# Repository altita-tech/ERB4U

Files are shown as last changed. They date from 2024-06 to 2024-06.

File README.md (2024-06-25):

# ERB API & Example Code

 


- [English](README.md)
- [中文](README.zh-CN.md)

* **The ERB4U series is a relay module programmable via USART serial port.**
* **A PC needs only one USB Type-C cable to simultaneously read/control multiple daisy-chained relay modules.**
* **Individual Relay Output:** Up to 30VDC/10A, 1NO + 1NC
* **Total Relay Output:** Up to 30VDC/32A
* **Working Principle:** The ERB4U device receives commands from USB or J1 connector (USART1) and passes the original commands to downstream ERB4U devices through the J6 connector (USART2) to achieve expandable functionality. Upon receiving a command, the ERB4U checks its own address and will only act if the address is correct.
* **USART Functionality**
    - **USART Parameters:** 115200 baud rate, 8 data bits, 1 stop bit, odd parity, no flow control
    - **Read Commands:** Temperature, relay status, PN/SN, and other information of single/multiple ERB4Us
    - **Write Commands:** Turn ON/OFF status of single/multiple relays
* **Address Setting:** 4-bit DIP switch sets addresses from 0 to 15, with multiple ERB4Us able to use the same address simultaneously
* **Protection Circuits**
    - Input reverse polarity protection
    - Optocoupler relay isolation between MCU and relay
    - Supports resistive (R) or inductive (L) loads
* **Python API & Example Code:** Available for download from GitHub
* **Operating Temperature:** -40 to 85 ℃

<table style="width:100%; text-align:center;">
  <tr>
    <td style="width: 50%;">
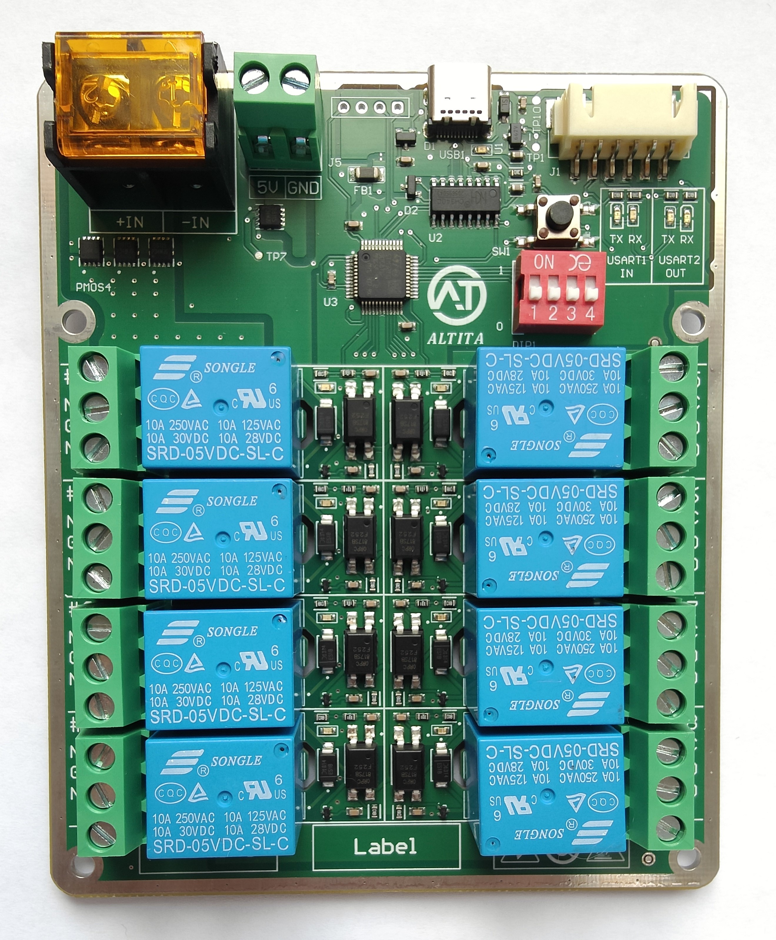
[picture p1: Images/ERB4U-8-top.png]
      
    </td>
    <td style="width: 50%;">
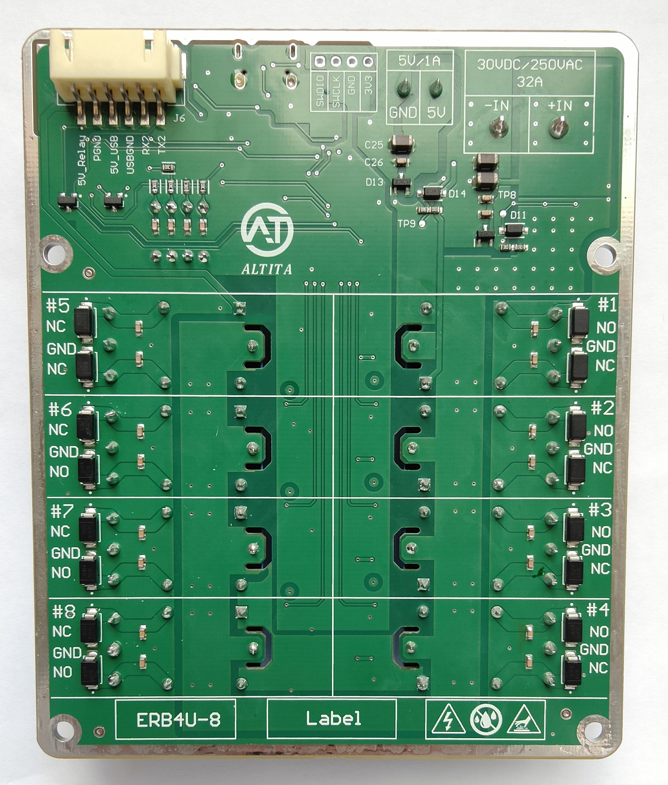
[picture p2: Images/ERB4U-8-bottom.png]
      
    </td>
  </tr>
</table>
<div style="text-align: center; margin: 10px;">
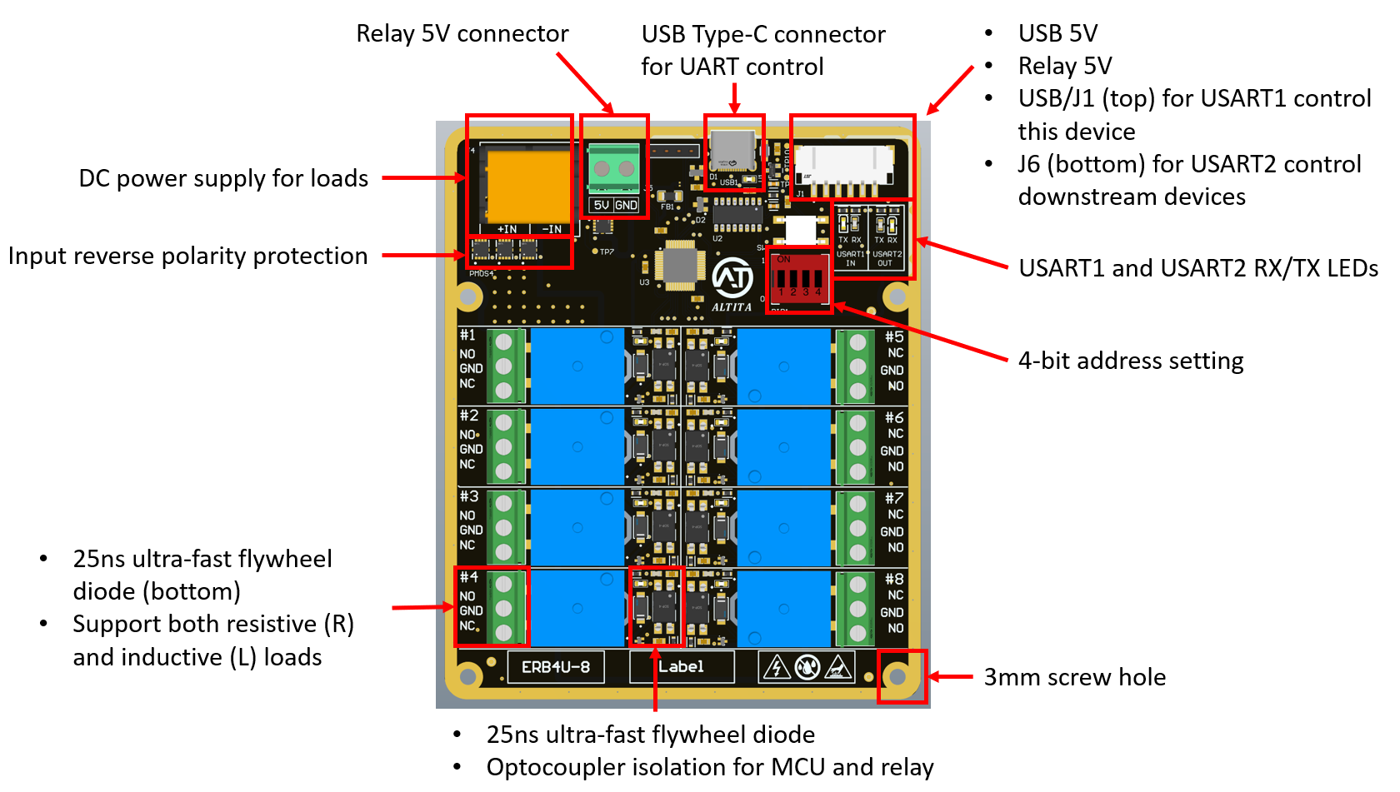
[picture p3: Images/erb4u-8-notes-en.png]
    
</div>

<div style="text-align: center; margin: 10px;">
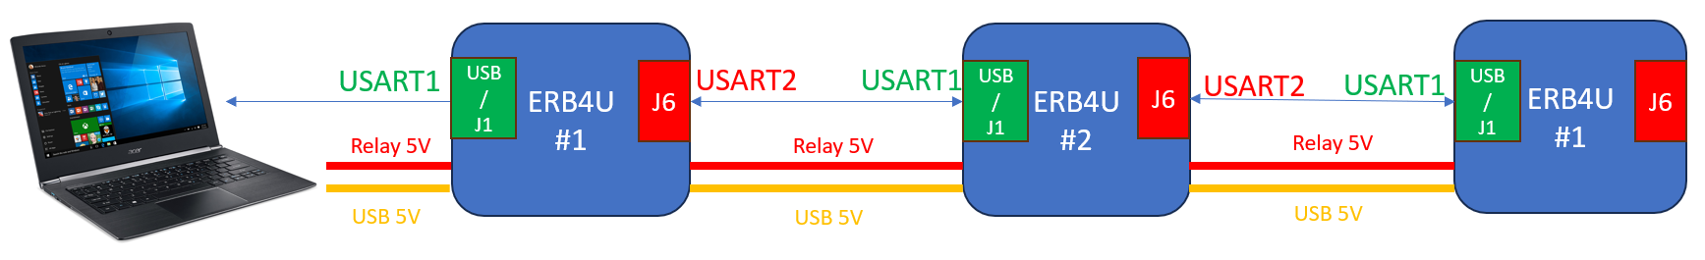
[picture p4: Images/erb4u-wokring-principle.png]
    
</div>

<table style="width:100%; text-align:center;">
  <tr>
    <td style="width: 50%;">
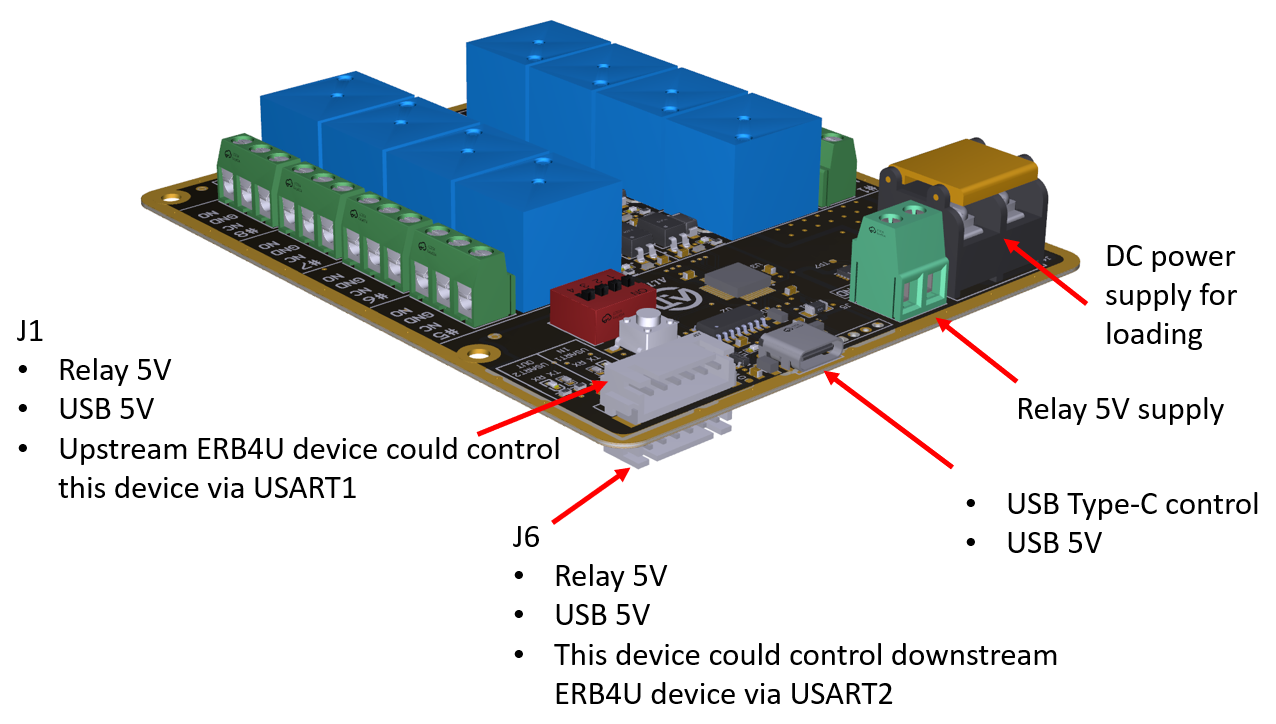
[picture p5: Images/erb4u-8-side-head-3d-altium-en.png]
      
    </td>
    <td style="width: 50%;">
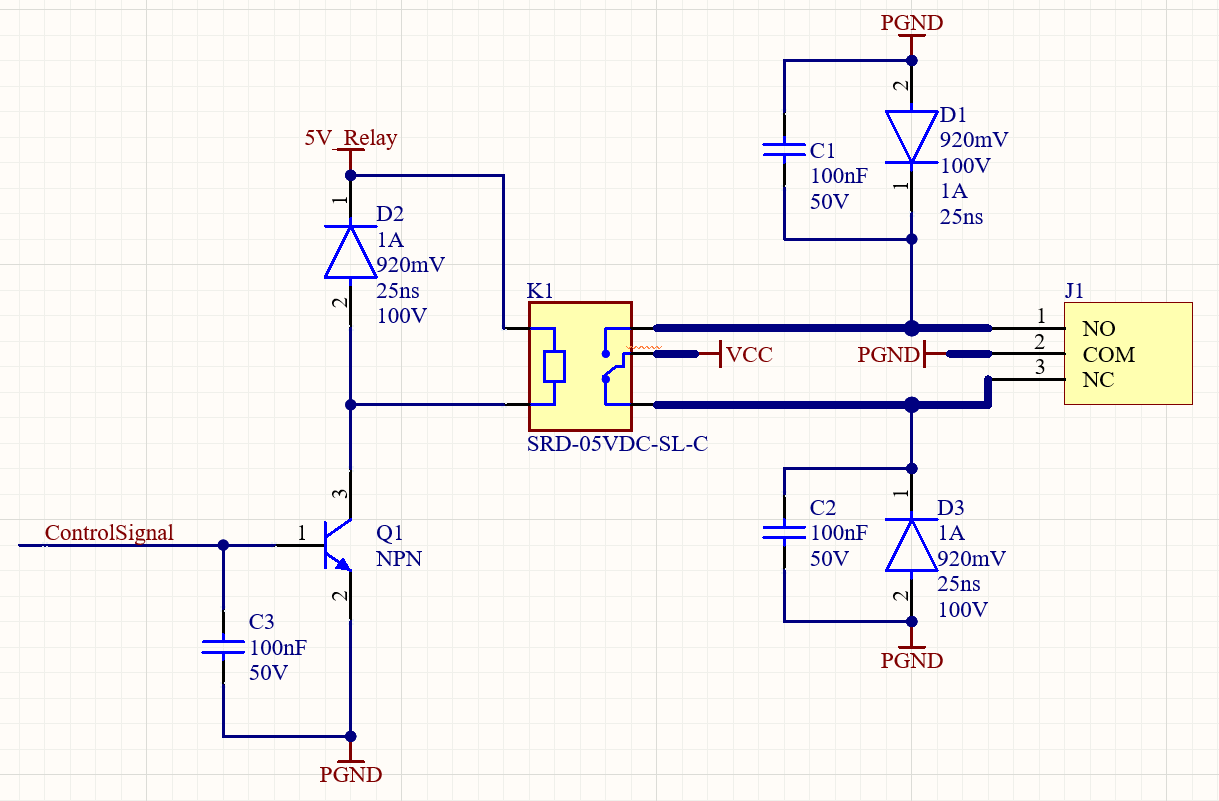
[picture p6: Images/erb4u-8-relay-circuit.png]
      
    </td>
  </tr>
</table>

## Communication Protocol
### Read Command
<div style="display: flex; justify-content: center;">
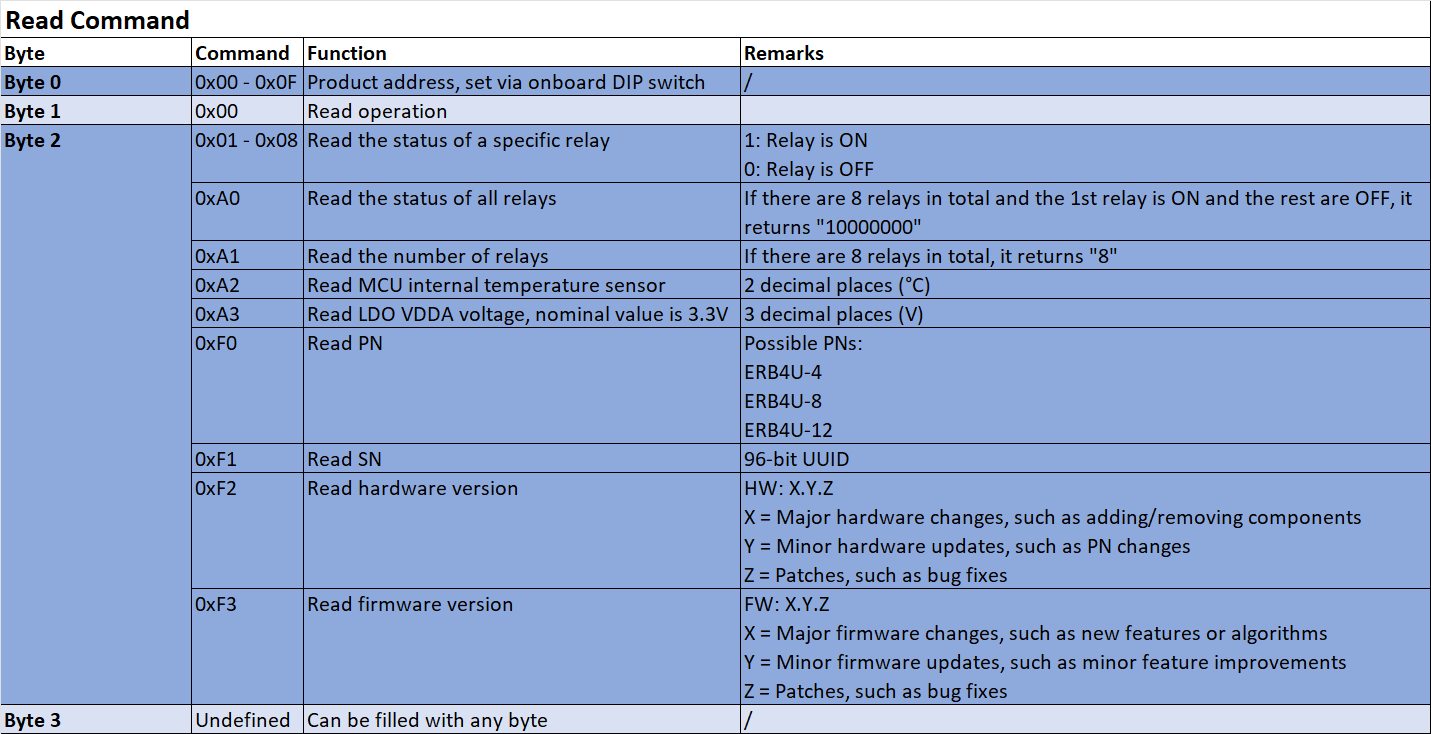
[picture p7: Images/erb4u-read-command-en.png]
  
</div>

### Write Command
<div style="display: flex; justify-content: center;">
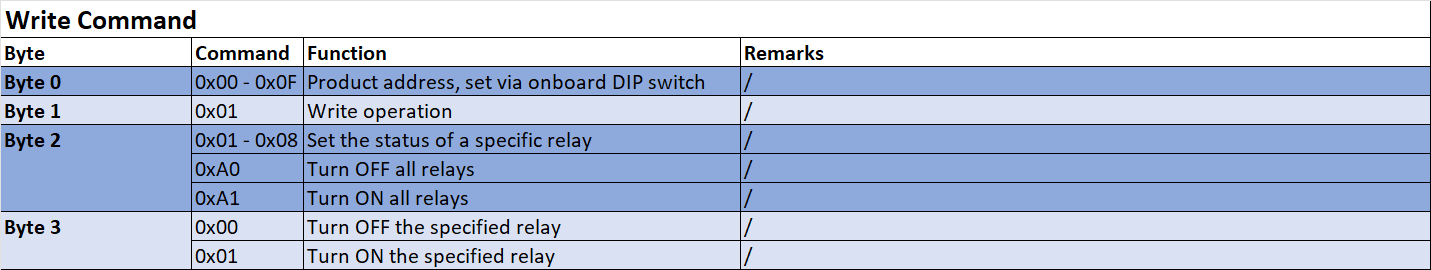
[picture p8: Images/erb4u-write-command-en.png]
  
</div>

### Error Message
<div style="display: flex; justify-content: center;">
  
</div>

## Drawings
### 2D Drawings: [Download](https://altita-tech.com/wp-content/uploads/ERB4U/ERB4U-8%202D.zip)
<table style="width:100%; text-align:center;">
  <tr>
    <td style="width: 50%; padding: 10px;">
      <div style="display: flex; justify-content: center;">
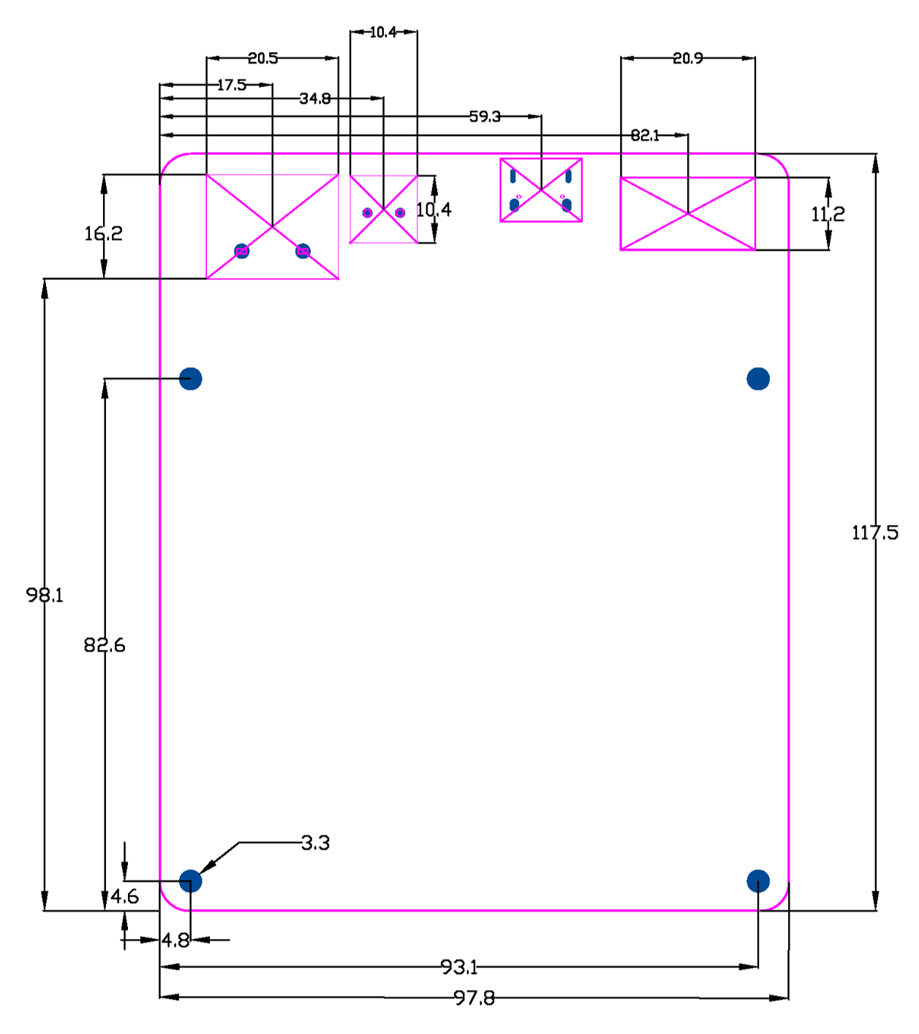
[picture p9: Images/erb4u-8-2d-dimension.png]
        
      </div>
    </td>
  </tr>
</table>

### 3D Model: [Download](https://altita-tech.com/wp-content/uploads/PBT223/PBT223%203D.zip)
<table style="width:100%; text-align:center;">
  <tr>
    <td style="width: 40%;">
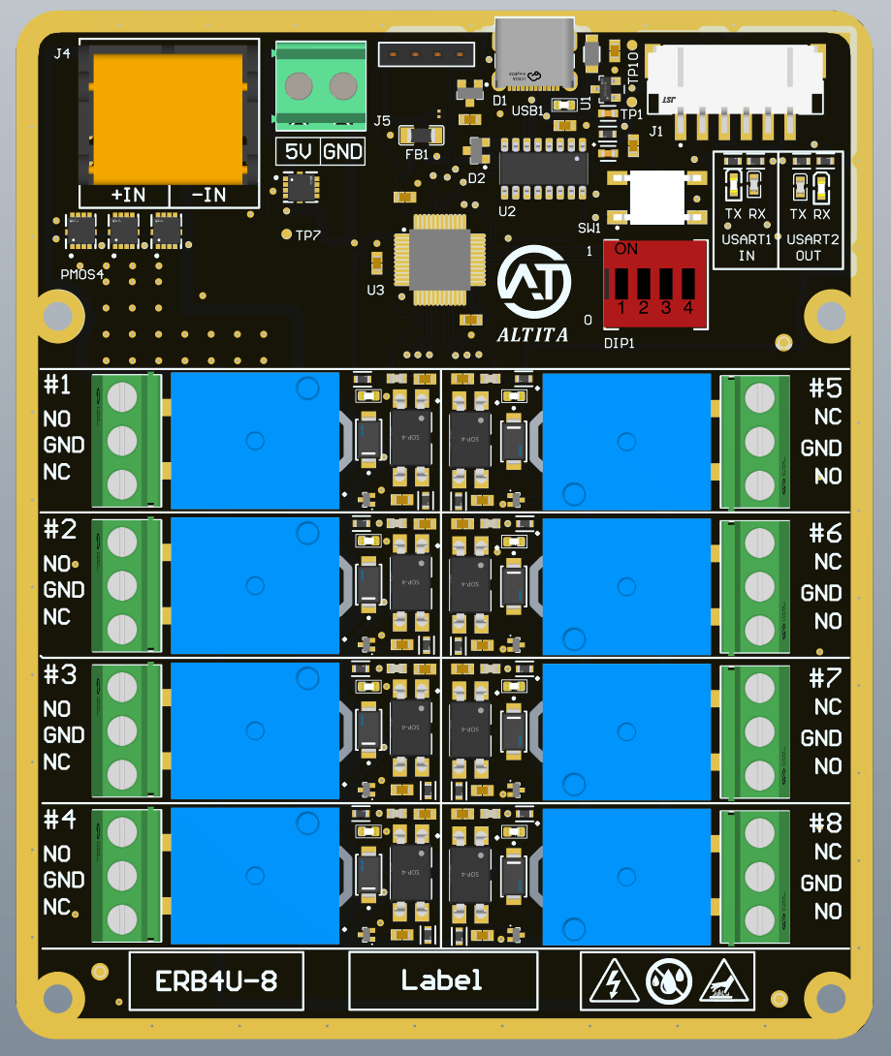
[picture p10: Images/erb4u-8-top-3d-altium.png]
      
    </td>
    <td style="width: 40%;">
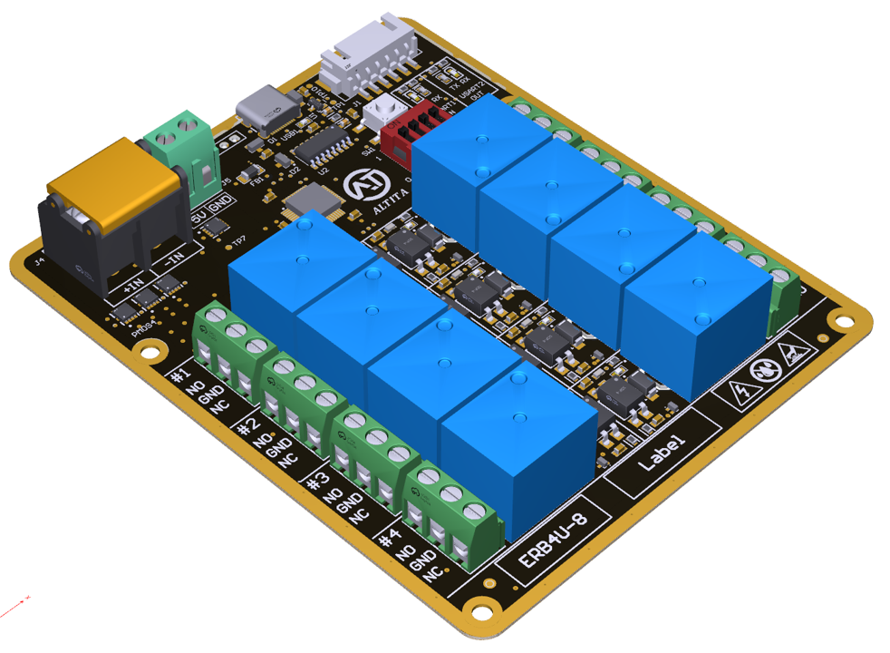
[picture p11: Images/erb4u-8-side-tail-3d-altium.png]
      
    </td>
  </tr>
</table>

## Functional Block Diagram
<table style="width:100%; text-align:center;">
  <tr>
    <td style="width: 100%;">
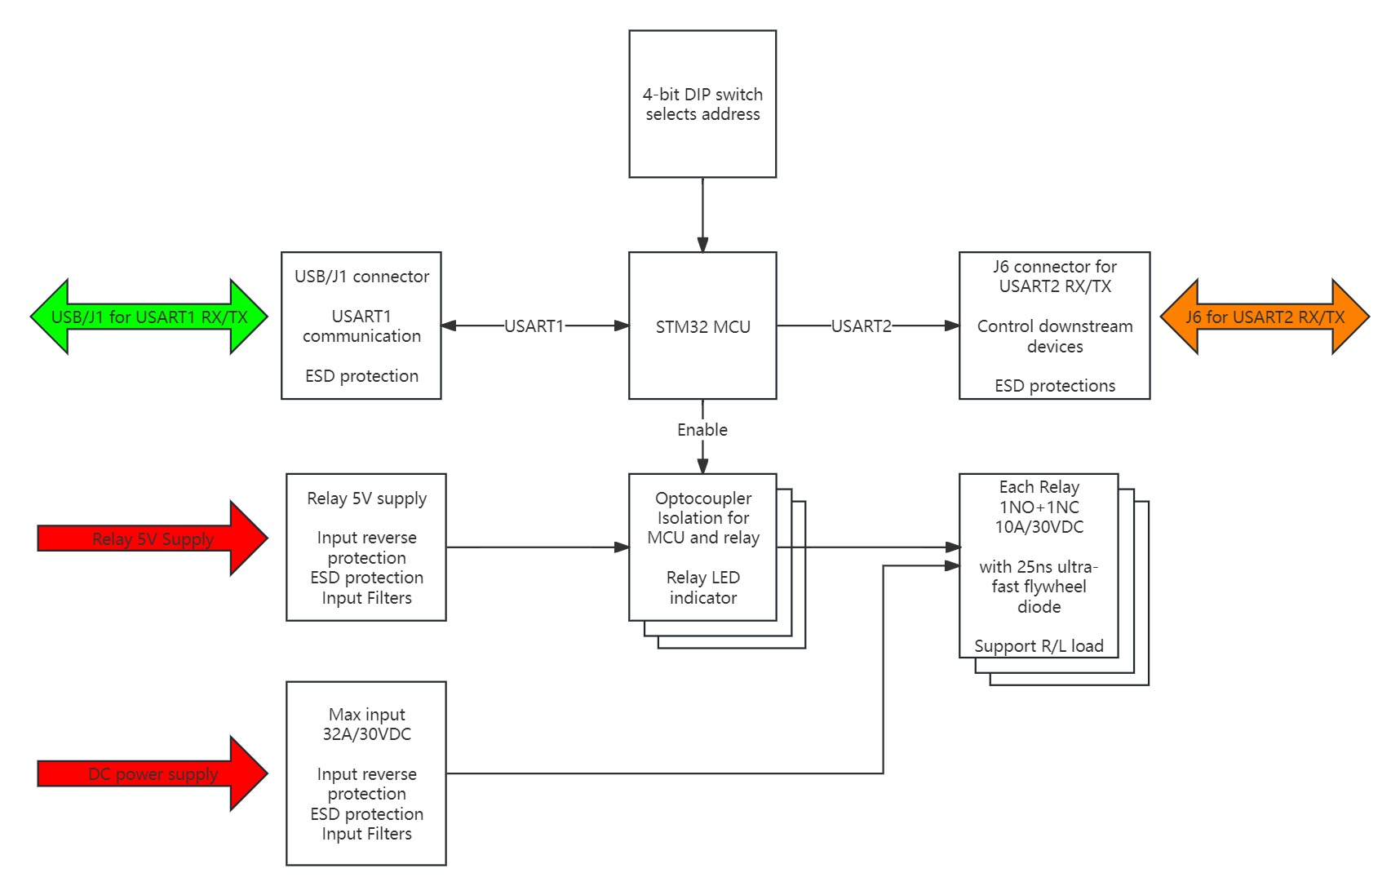
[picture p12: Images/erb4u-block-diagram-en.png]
      
    </td>
  </tr>
</table>

## Video Tutorial
YouTube Video (https://www.youtube.com/watch?v=MFrZ_5qzL38)

## Contact Us
<div style="display: flex; justify-content: space-between; align-items: flex-start;">
  <div>
    <ul style="list-style-type: disc; padding-left: 20px; margin: 0;">
      <li><strong>Company Website:</strong> <a href="https://altita-tech.com/">https://altita-tech.com/</a></li>
      <li><strong>Sales:</strong> <a href="mailto:sales@altita-tech.com">sales@altita-tech.com</a></li>
      <li><strong>Technical Support:</strong> <a href="mailto:tech@altita-tech.com">tech@altita-tech.com</a></li>
    </ul>
  </div>
</div>

<table style="width:100%; text-align:center;">
  <tr>
    <td style="width: 100%;">
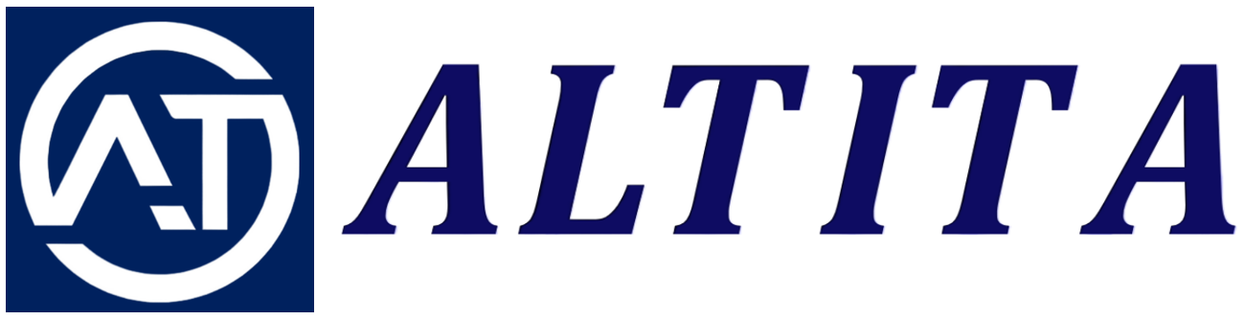
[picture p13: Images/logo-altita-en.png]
      
    </td>
  </tr>
</table>

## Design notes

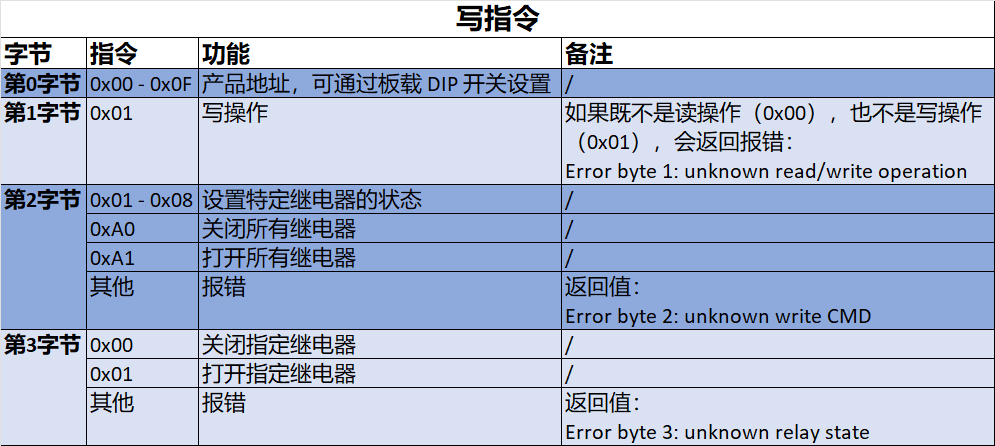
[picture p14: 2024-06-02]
Images/erb4u-write-command-cn.png

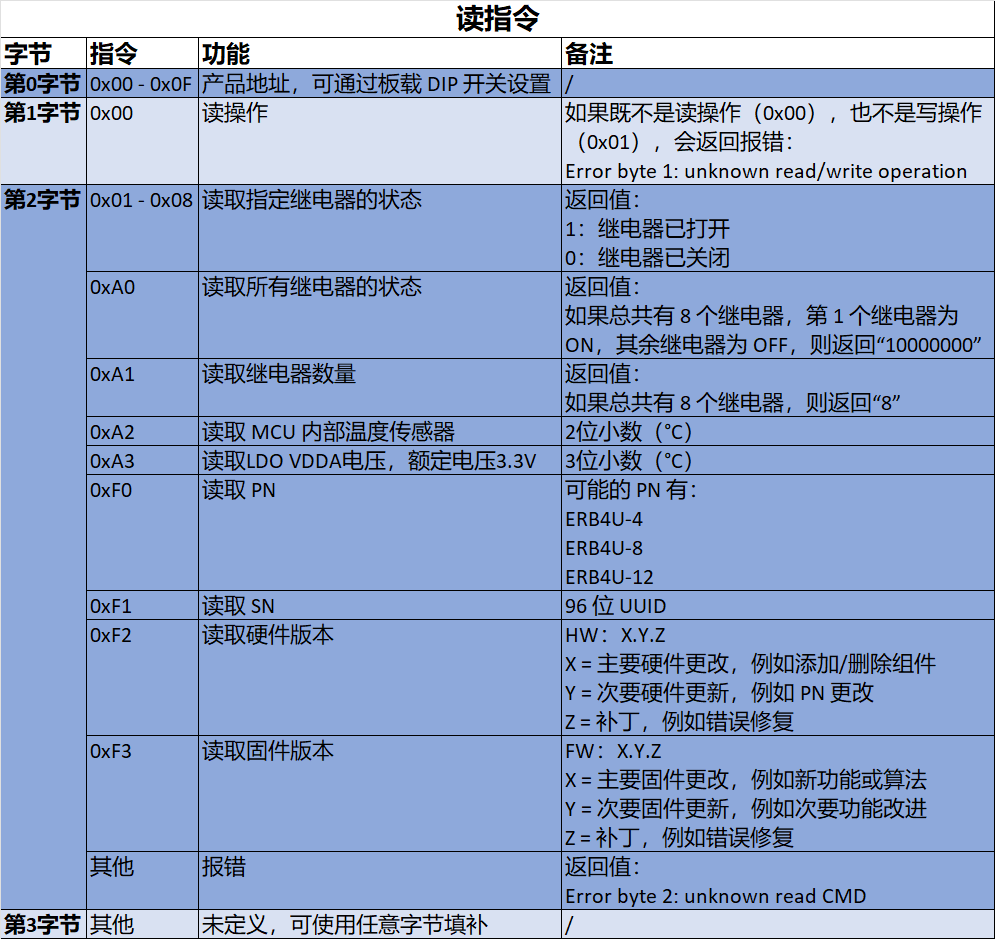
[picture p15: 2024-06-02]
Images/erb4u-read-command-cn.png

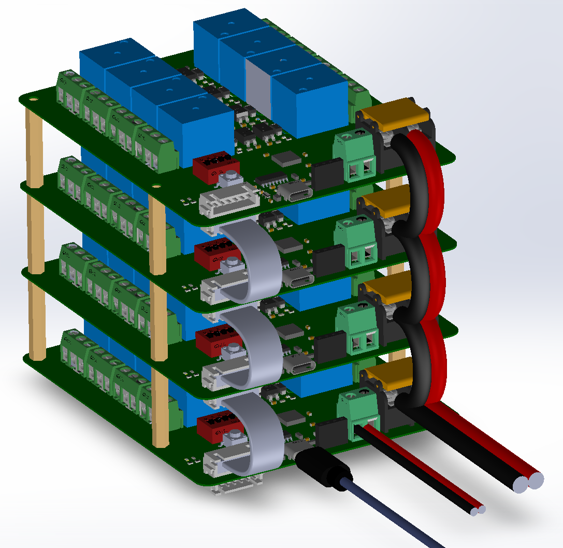
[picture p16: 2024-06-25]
Images/erb4u-8-layers-3d-solidworks.png

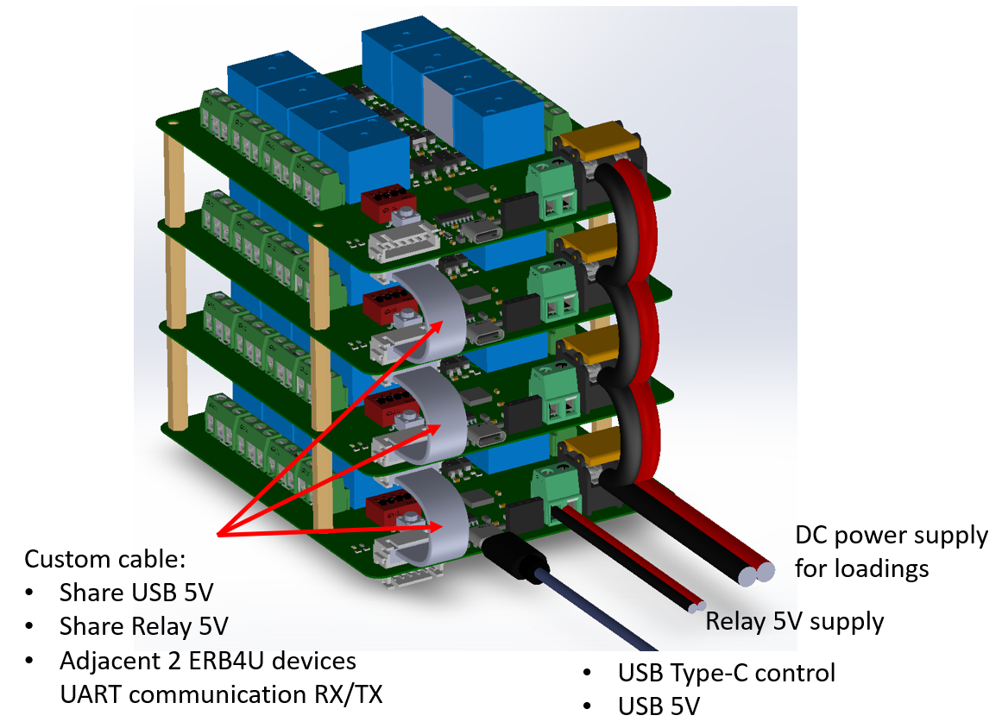
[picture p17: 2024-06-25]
Images/erb4u-8-layers-3d-solidworks-en.png

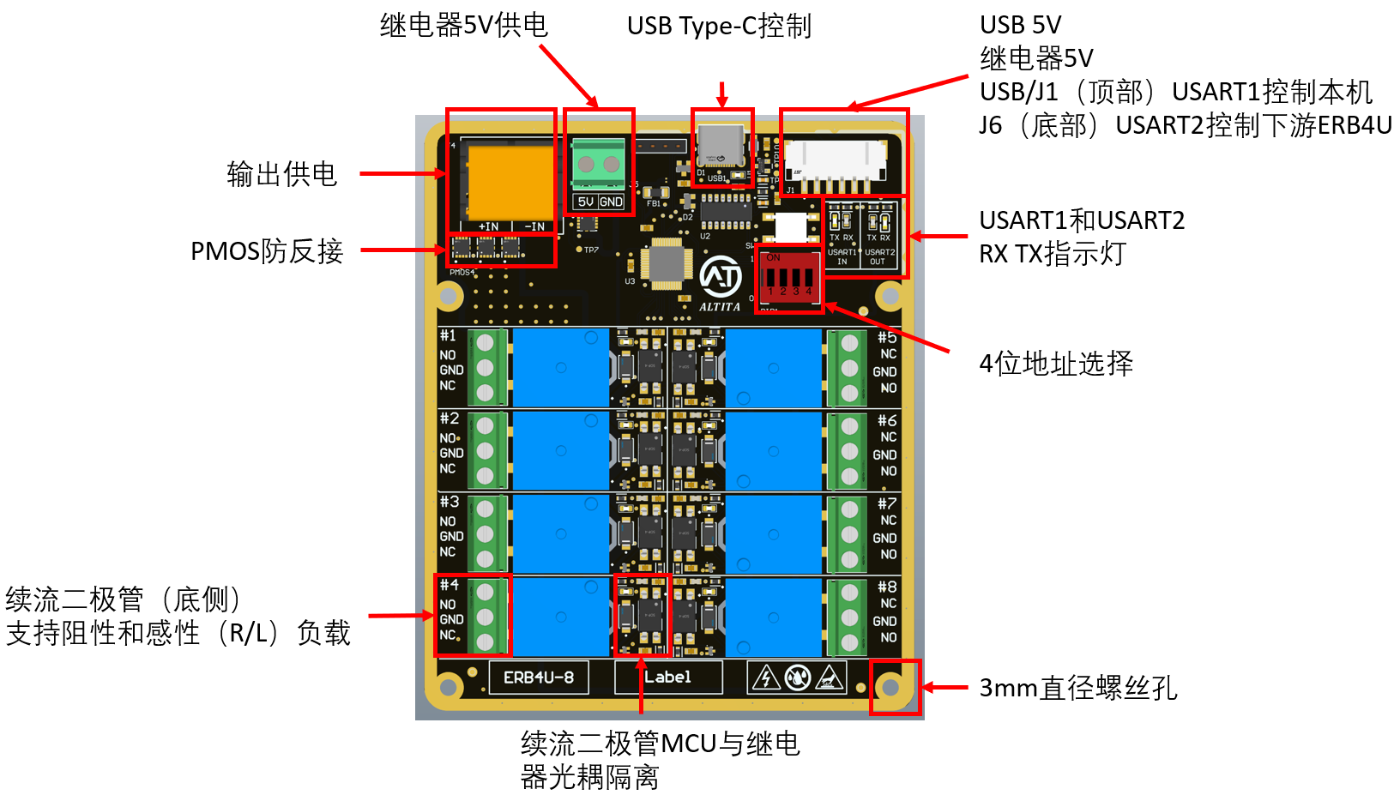
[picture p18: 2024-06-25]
Images/erb4u-8-notes-cn.png

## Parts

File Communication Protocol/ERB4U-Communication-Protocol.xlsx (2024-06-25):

Read Command
Byte | Command | Function | Remarks
Byte 0 | 0x00 - 0x0F | Product address, set via onboard DIP switch | /
Byte 1 | 0x00 | Read operation
Byte 2 | 0x01 - 0x08 | Read the status of a specific relay | 1: Relay is ON 0: Relay is OFF
 | 0xA0 | Read the status of all relays | If there are 8 relays in total and the 1st relay is ON and the rest are OFF, it returns "10000000"
 | 0xA1 | Read the number of relays | If there are 8 relays in total, it returns "8"
 | 0xA2 | Read MCU internal temperature sensor | 2 decimal places (°C)
 | 0xA3 | Read LDO VDDA voltage, nominal value is 3.3V | 3 decimal places (V)
 | 0xF0 | Read PN | Possible PNs: ERB4U-4 ERB4U-8 ERB4U-12
 | 0xF1 | Read SN | 96-bit UUID
 | 0xF2 | Read hardware version | HW: X.Y.Z X = Major hardware changes, such as adding/removing components Y = Minor hardware updates, such as PN changes Z = Patches, such as bug fixes
 | 0xF3 | Read firmware version | FW: X.Y.Z X = Major firmware changes, such as new features or algorithms Y = Minor firmware updates, such as minor feature improvements Z = Patches, such as bug fixes
Byte 3 | Undefined | Can be filled with any byte | /
Write Command
Byte | Command | Function | Remarks
Byte 0 | 0x00 - 0x0F | Product address, set via onboard DIP switch | /
Byte 1 | 0x01 | Write operation | /
Byte 2 | 0x01 - 0x08 | Set the status of a specific relay | /
 | 0xA0 | Turn OFF all relays | /
 | 0xA1 | Turn ON all relays | /
Byte 3 | 0x00 | Turn OFF the specified relay | /
 | 0x01 | Turn ON the specified relay | /
Error Message
Byte 1 Error | Error byte 1: unknown read/write operation
Byte 2 Error (Read) | Error byte 2: unknown read CMD
Byte 2 Error (Write) | Error byte 2: unknown write CMD
Byte 3 Error (Write) | Error byte 3: unknown relay state

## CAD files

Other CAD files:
2D/erb4u-8-2d-dxf.dxf
2D/erb4u-8-2d-dwg.DWG

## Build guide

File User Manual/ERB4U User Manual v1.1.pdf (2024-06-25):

www.altita-tech.com

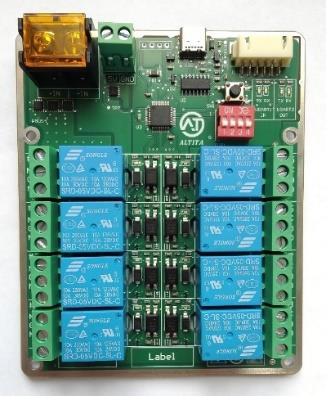
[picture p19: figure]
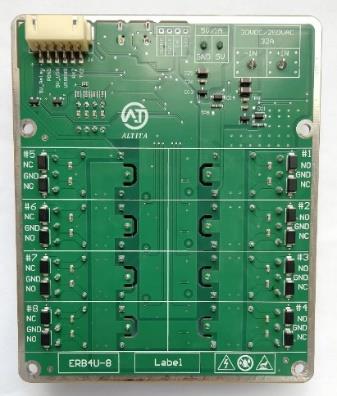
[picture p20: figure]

Copyright ©2024 奥提塔（上海）电子科技有限公司 | 1

# ERB4U Relay Module User Manual

# Extensible, Programmable, Max 30VDC/32A

# Product Overview

ERB4U series is a relay module that can be programmed through a USART serial port. Only 1 USB Type-C cable is required to read/control multiple relay modules simultaneously.

- Each Relay: max 30VDC/10A, 1 NO + 1 NC
- Total Relays: max 30VDC/32A
- Working Principle: The ERB4U device receives USART commands from the USB or J1 connector (USART1) and passes the original USART commands to downstream ERB4U devices through the J6 connector (USART2). Therefore, multiple ERB4U modules can be controlled by 1 USB type-C cable from PC. Upon receiving a command, the ERB4U will check its local address and will only execute the action if the address matches.
- USART Functionality
- USART Parameters: 115200 baud rate, 8 data bits, 1 stop bit, odd parity, no flow control
- Read Commands: read temperature, 1 or multiple relay status, PN/SN, etc
- Write Commands: turn ON/OFF 1 or multiple relays
- Address Setting: 4-bit DIP Switch: Sets the address from 0 to 15; multiple ERB4Us can share the same address.
- Protection Circuits
- Input Reverse Polarity Protection
- Optocoupler Relay Isolation: between MCU and relay
- Output Protection: support resistive (R) or inductive (L) loads
- Python API & Example Codes: can be downloaded from GitHub
- Operating Temperature: -40 to 85 ℃
Figure 1 ERB4U-8 real top | Figure 2 ERB4U-8 real bottom

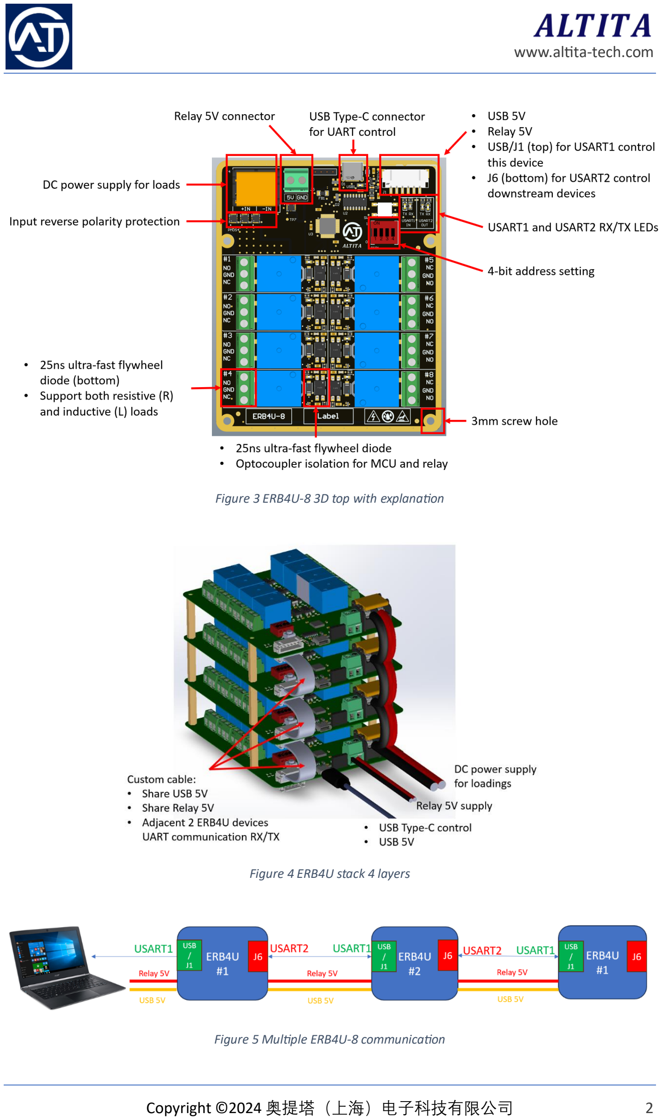
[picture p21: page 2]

Figure 3 ERB4U-8 3D top with explanation

Figure 4 ERB4U stack 4 layers

Figure 5 Multiple ERB4U-8 communication

# Applications

- Industrial Automation Control
- Automated Test Equipment
- Embedded Electronic Devices
- Universities, Research Institutions, Laboratories
- STEM Education, Training Institutes

# Version Control

Version | Release Date | Description and Changes
1.0 | May 1, 2024 | Initial release version
1.1 | May 30, 2024 | Added command for reading LDO VDDA

## Table of Content

## 1 Electrical Parameters

### 1.1 Relays

- Upon startup, all relays are OFF by default
- Each relay output: max 30VDC/10A, 1 NO + 1 NC
- Optocoupler relay isolation between MCU and relay
- Relay output includes a 25ns ultra-fast freewheeling diode, supporting both resistive and inductive loads (e.g., solenoids, motors)

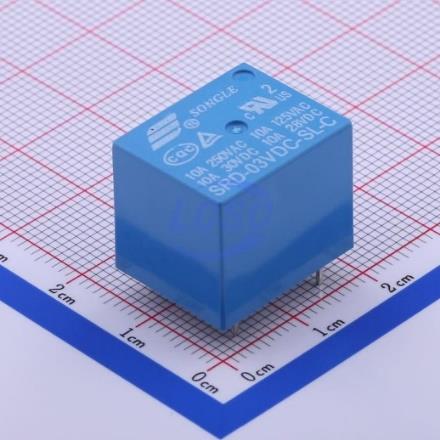
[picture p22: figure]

Figure 6 Relay 30VDC/10A

### 1.2 Address Setting

Manually select device address via 4-bit DIP switch, ranging from 0x00 to 0x0F.

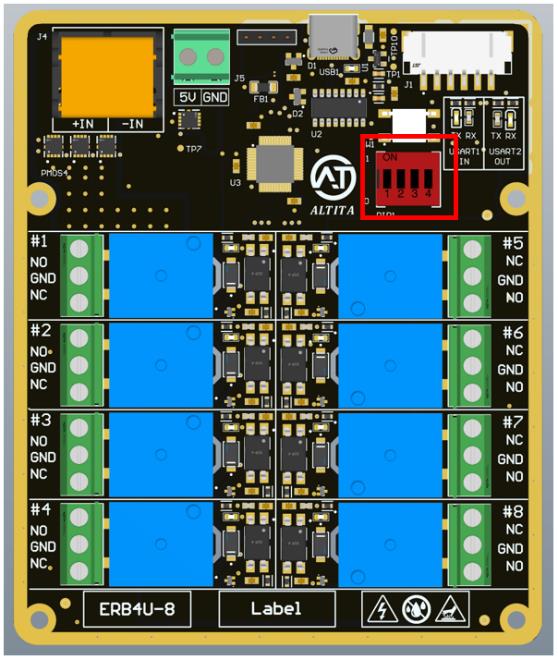
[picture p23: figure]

Figure 7 ERB4U 4-bit DIP switch

### 1.3 USART Communication

Only need 1 single USB Type-C cable connects the PC to the ERB4U module, enabling USART serial read/write functionality.

Parameter | Value
Communication Mode | • USART1 connects to USB Type-C and J1 connector for communication with PC or upstream ERB4U relay module • USART2 connects to J6 connector for communication with downstream ERB4U relay module.
Baud Rate | 115200
Data Bits | 8
Stop Bits | 1
Parity | Odd
Flow Control | None
If additional relays are needed, connect the upstream ERB4U's J6 connector to the downstream ERB4U's J1 connector using a custom cable (PN: S108520017, Manufacturer: Ckmtw). The operational principle is as follows:
- USB and J1 connector (top) connect to USART1.
- J6 connector (bottom) connects to USART2.
- When the PC or upstream ERB4U module sends a write command to the ERB4U, the command is received via USB or J1 connector (USART1) and then transmitted to the next ERB4U via J6 connector (USART2), enabling expandability.
- The custom cable is used for sharing USB 5V and relay 5V power, also used for USART RX/TX communication between 2 adjacent ERB4U modules.
- Upon receiving the command, the ERB4U checks its address. If the address matches, the ERB4U executes the corresponding action. If not, the command is ignored.
- For specific USART commands, refer to the section <Communication Protocol>.

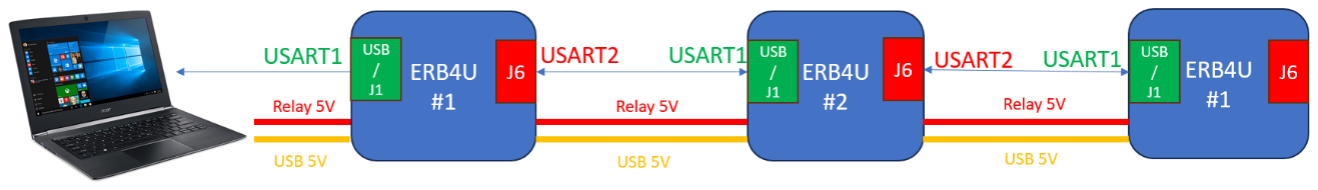
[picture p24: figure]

Figure 8 Multiple ERB4U-8 communication

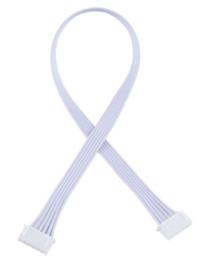
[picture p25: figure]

Figure 9 Custom cable for multiple ERB4U communication

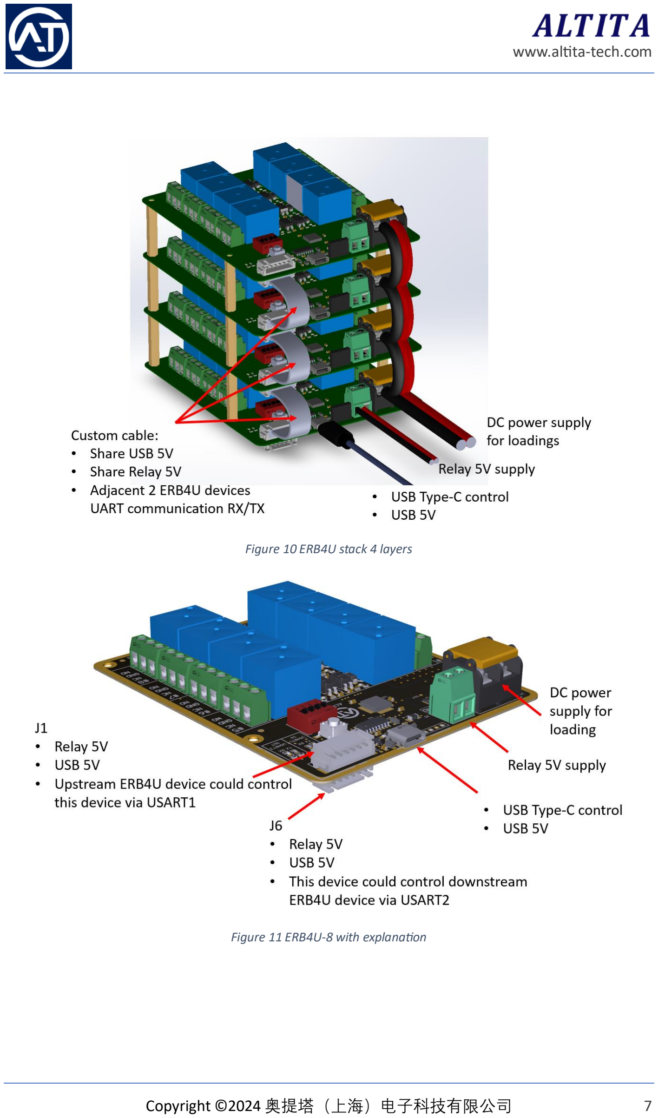
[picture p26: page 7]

Figure 10 ERB4U stack 4 layers

Figure 11 ERB4U-8 with explanation

### 1.4 LED

- USB Power: green LED
- Relay Status: green LED
- USART1 TX: blue LED
- USART1 RX: yellow LED
- USART2 RX: blue LED
- USART2 TX: yellow LED

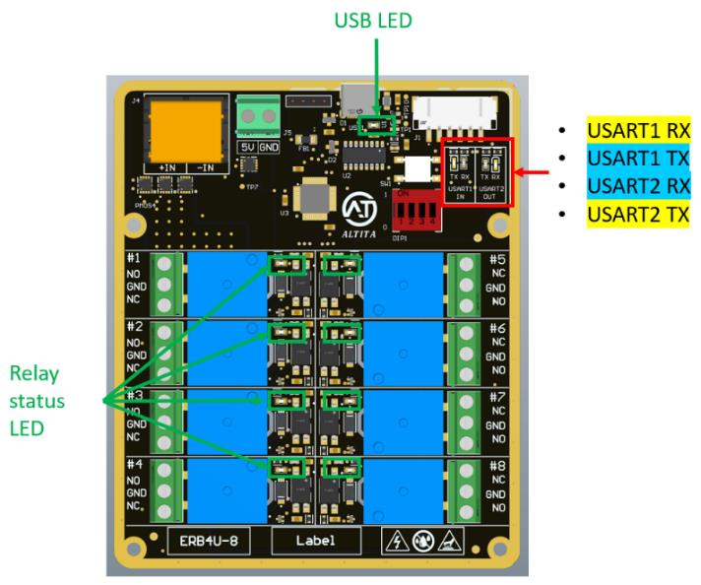
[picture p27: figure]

Figure 12 ERB4U-8 LEDs

### 1.5 Reset Button

- Pressing the reset button restarts the MCU, and all relays return to their default OFF state.

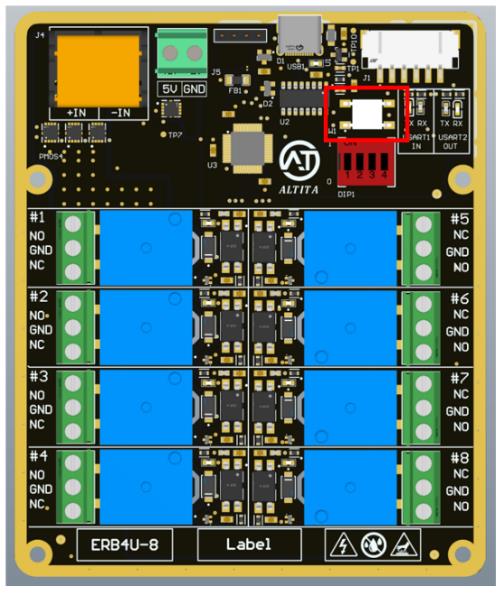
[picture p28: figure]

Figure 13 ERB4U-8 reset button

### 1.6 Operating Temperature

- -40 to 85 ℃
- The MCU internal temperature sensor will measure the temperature value, and you may obtain the temperature value via UART command (Python API).

## 2. Protection Circuits

### 2.1 Input Reverse Polarity Protection

- Both relay 5V connector and DC power connector have reverse input protection.
- Due to the conduction resistance Rds_on of PMOS, PMOS IC heats up when current flows through it. Typically, the PMOS is the hottest area on the ERB4U module. The temperature can be calculated using the following formula:

PMOS Temperature = Room Temperature + (Loading Current)^2 *0.4133

- Temperature Unit: Degree Celsus ℃
- Current Unit: A

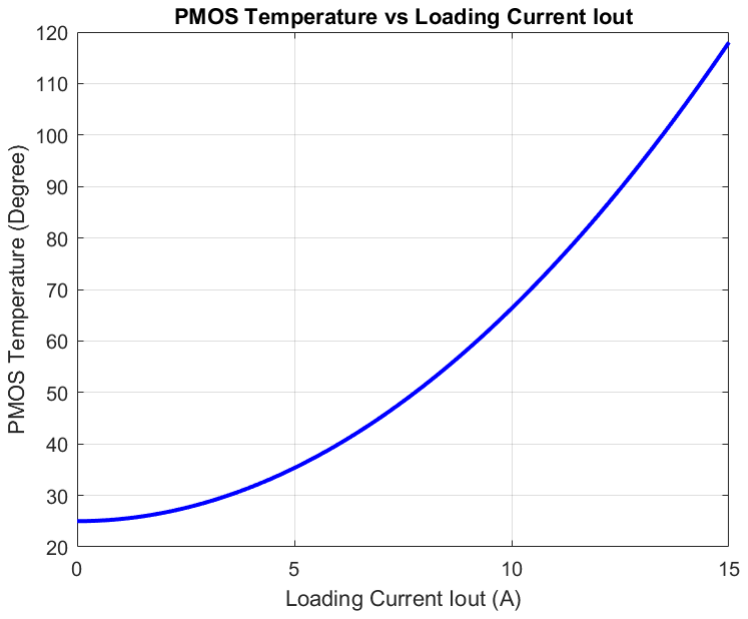
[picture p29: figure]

- It is recommended that the total continuous input current < 15A.
- If the total input current > 15A, a heat sink or cooling fan is required for PMOS.

### 2.2 Optocoupler Relay Isolation between MCU and Relay

Since the MCU operates at a low voltage of 3.3V and low current (mA level), while the relay operates at the high voltage and high current (such as 24VDC, 10A), an Optocoupler relay is used for isolation between MCU and relay.

- The MCU uses a 0V or 3.3V GPIO to enable of disable the Optocoupler relay.
- The Optocoupler relay output is 5V, which is used to activate the relay.

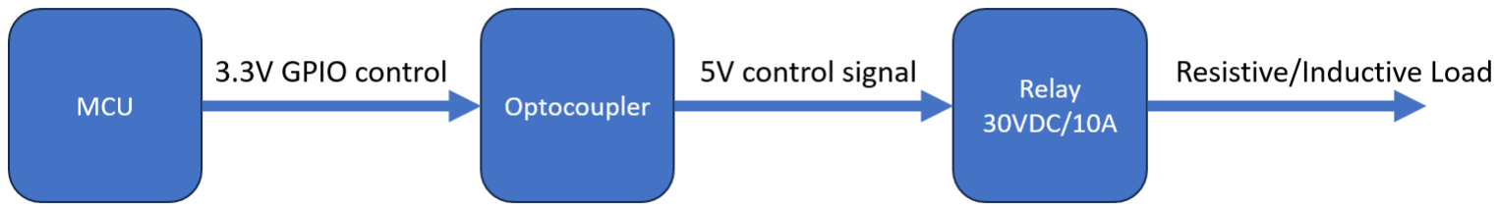
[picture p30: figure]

Figure 14 Optocoupler relay isolation between MCU and relay

### 2.3 Support Resistive (R) and Inductive (L) Loads

- For inductive loads (e.g., solenoids, motors), energy stores in the inductor while current pass through the load. When the relay suddenly turns off, the inductive load generates a very high back EMF due to the inductive characteristics. This transient reverse voltage can far exceed the normal operating voltage.
- If the continuous loading current is HIGH, you probably can see electrical spikes and arcs.
- After long time operation, the relay contacts might become blackened or stick together, leading to relay malfunction (cannot turn ON/OFF properly).
- The pure resistive load does not have this problem.

To address these issues, a 25ns ultra-fast flyback diode and a capacitor is included on output sides of the relay. This diode can quickly dissipate the energy from the inductor within 25ns, resolving the back EMF and arcing problems from inductive loads.

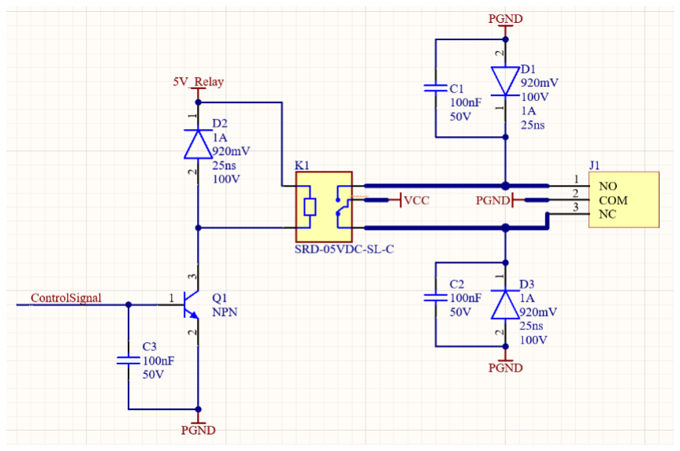
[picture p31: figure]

Figure 15 ERB4U relay schematic support R/L loads

## 3. Communication Protocol

### 3.1 Read Command

Read Command
Byte | Command | Function | Remarks
Byte 0 | 0x00 - 0x0F | Product address, set via onboard DIP switch | /
Byte 1 | 0x00 | Read operation | /
| | relay | 1: Relay is ON 0: Relay is OFF
| 0xA0 | Read the status of all relays | If there are 8 relays in total and the 1st relay is ON and the rest are OFF, it returns "10000000"
| 0xA1 | Read the number of relays | If there are 8 relays in total, it returns "8"
| 0xA2 | Read MCU internal temperature sensor | 2 decimal places (°C)
| 0xA3 | Read LDO VDDA voltage, nominal value is 3.3V | 3 decimal places (V)
| 0xF0 | Read PN | Possible PNs: ERB4U-4 ERB4U-8 ERB4U-12
| 0xF1 | Read SN | 96-bit UUID
| 0xF2 | Read hardware version | HW: X.Y.Z X = Major hardware changes, such as adding/removing components Y = Minor hardware updates, such as PN changes Z = Patches, such as bug fixes
| 0xF3 | Read firmware version | FW: X.Y.Z X = Major firmware changes, such as new features or algorithms Y = Minor firmware updates, such as minor feature improvements Z = Patches, such as bug fixes
Byte 3 | Undefined | Can be filled with any byte | /
Byte 2 | 0x01 - 0x08 | Read the status of a specific

### 3.2 Write Command

Write Command
Byte | Command | Function | Remarks
Byte 0 | 0x00 - 0x0F | Product address, set via onboard DIP switch | /
Byte 1 | 0x01 | Write operation | /
Byte 2 | 0x01 - 0x08 | Set the status of a specific relay | /
| 0xA0 | Turn OFF all relays | /
| 0xA1 | Turn ON all relays | /
Byte 3 | 0x00 | Turn OFF the specified relay | /
| 0x01 | Turn ON the specified relay | /

### 3.3 Error Message

Error Message
Byte | Error Message
Byte 1 Error | Error byte 1: unknown read/write operation
Byte 2 Error (Read) | Error byte 2: unknown read CMD
Byte 2 Error (Write) | Error byte 2: unknown write CMD
Byte 3 Error (Write) | Error byte 3: unknown relay state

## 4. Functional Block Diagram

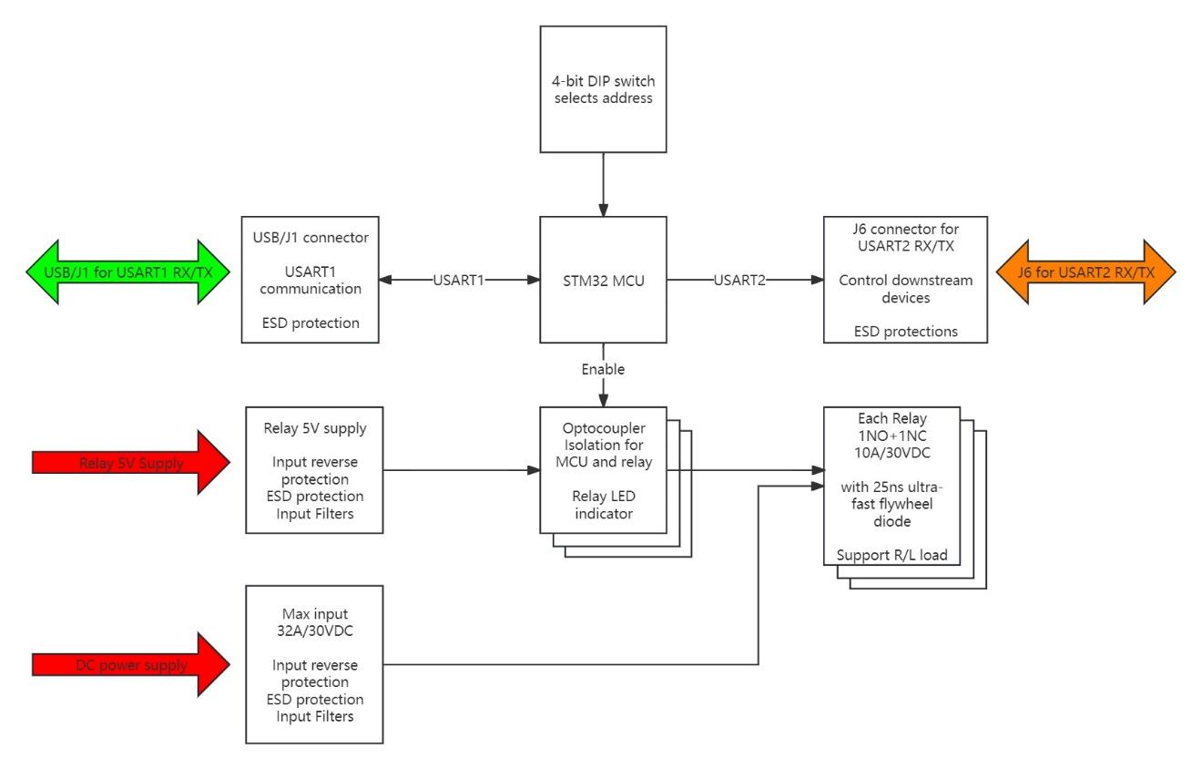
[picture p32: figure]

Figure 16 ERB4U functional block diagram

## 5. Product Images

### 5.1 Real Product Images

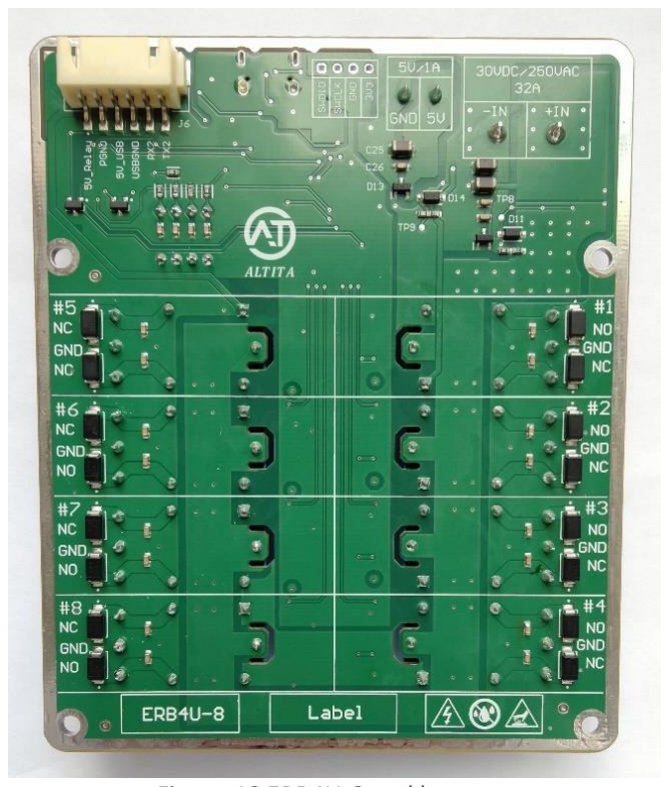
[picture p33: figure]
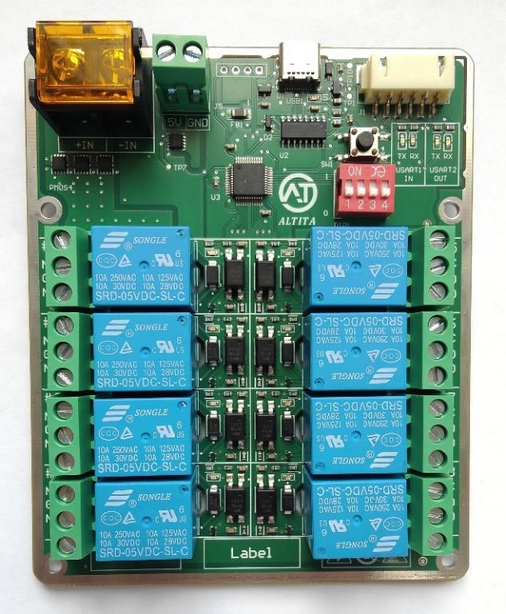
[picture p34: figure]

Figure 17 ERB4U-8 real top | Figure 18 ERB4U-8 real bottom

### 5.2 2D Drawings

- Download: DWG, DXF, PNG
- Unit: mm

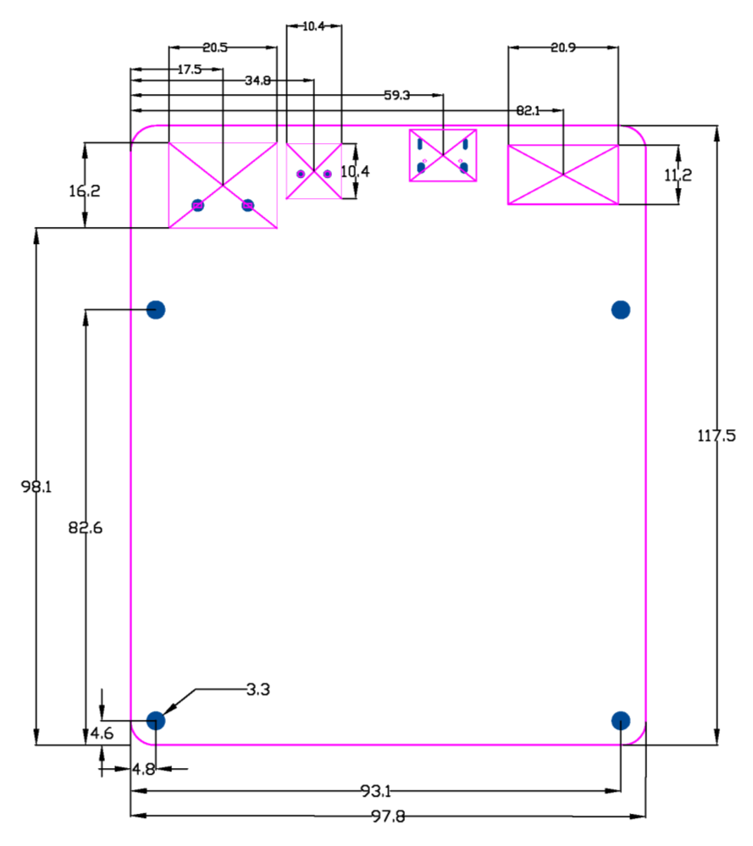
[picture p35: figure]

Figure 19 ERB4U-8 2D with dimension

### 5.3 3D Models

- Download: STEP, PDF 3D

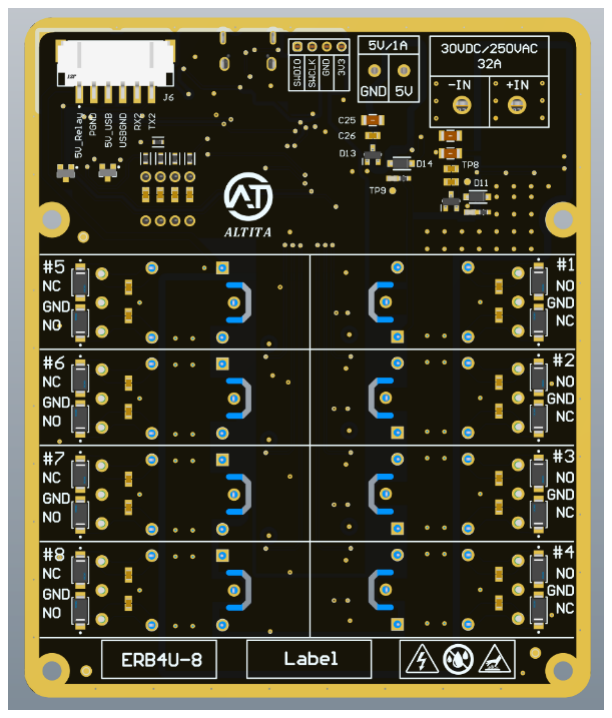
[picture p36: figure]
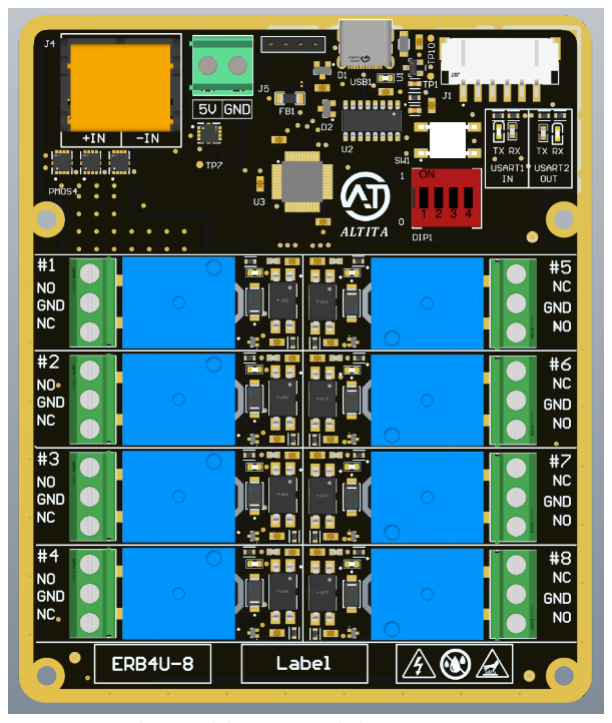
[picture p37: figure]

Figure 20 ERB4U-8 3D Top | Figure 21 ERB4U-8 3D Bottom

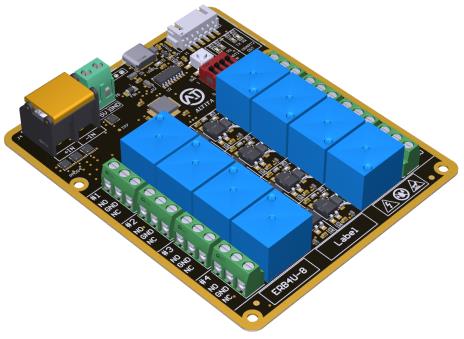
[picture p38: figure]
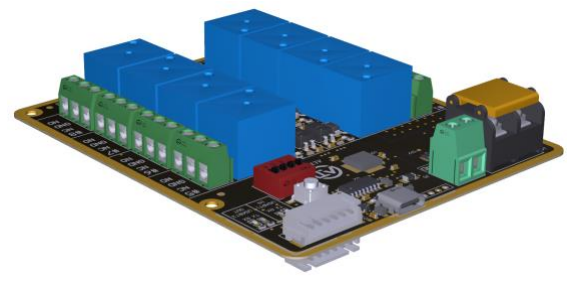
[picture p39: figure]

Figure 22 ERB4U-8 3D Side | Figure 23 RB4U-8 3D Side

## 6. Python API & Example Code

- GitHub Link (https://github.com/altita-tech/ERB4U)

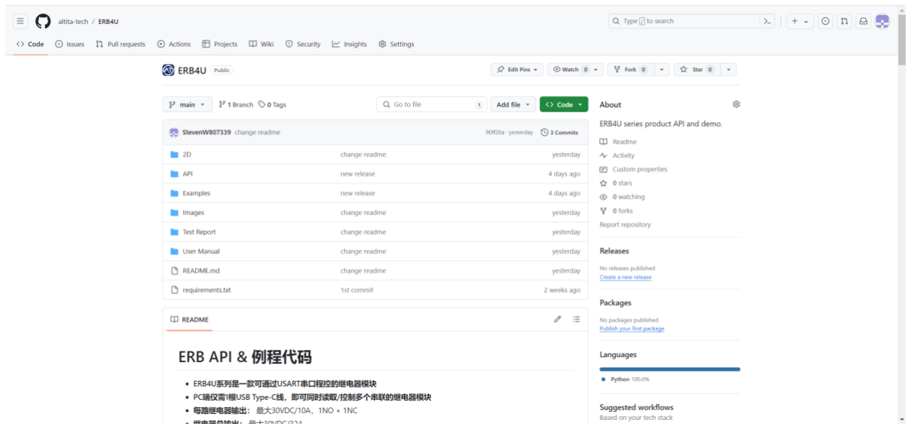
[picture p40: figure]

Figure 24 ERB4U GitHub repo

## 7. Test Report

- Download: ERB4U test report template

## 8. Contact Us

- Company Website: https: //altita-tech.com/
- Phone: +86 13512122992 (Sales: Ms. Dong)
- WeChat: DL13512122992 (Sales: Ms. Dong)
- Sales Email: sales@altita-tech.com
- Technical Support Email: tech@altita-tech.com

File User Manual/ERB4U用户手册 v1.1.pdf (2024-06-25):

www.altita-tech.com

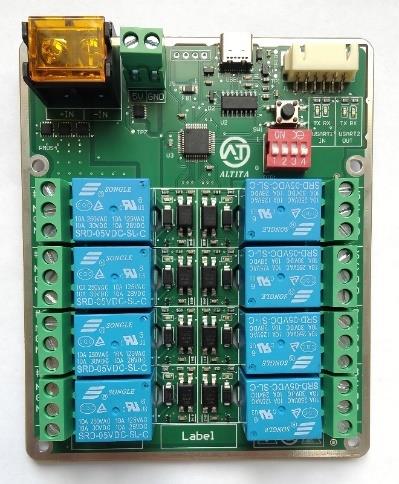
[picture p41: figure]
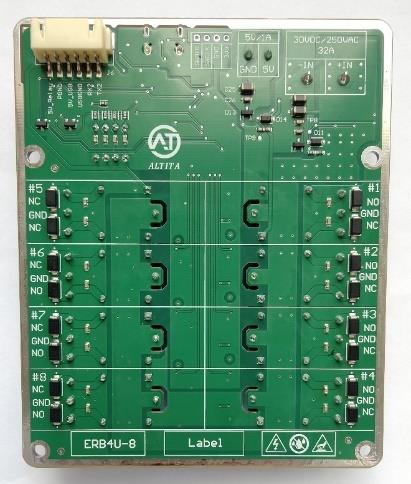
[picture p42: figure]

Copyright ©2024 奥提塔（上海）电子科技有限公司 | 1

# ERB4U 继电器模块 用户手册

# 可扩展，可编程，最大 30VDC /32A

# 产品简介

- ERB4U 系列是一款可通过 USART 串口程控的继电器模块
- PC 端仅需 1 根 USB Type-C 线，即可同时读取/控制多个串联的继电器模块。
- 每路继电器输出：最大 30VDC/10A，1NO + 1NC
- 继电器总输出：最大 30VDC/32A
- 工作原理：ERB4U 设备从 USB 或 J1 连接器（USART1）接收指令，并把原指令通过 J6 连接器（USART2）传递给下游 ERB4U 设备，实现可扩展功能。当接收到指令 后，ERB4U 会检查本机地址，只有当地址正确时，才会执行动作。
- USART 功能
- USART 参数： 115200 波特率，8 数据位，1 停止位，奇校验，无流控制
- 读取：单个/多个 ERB4U 的温度，继电器状态，PN/SN 等信息
- 控制：单个/多个继电器状态
- 地址设定：4 位拨码开关设定地址 0 – 15，多个 ERB4U 可同时使用一个地址
- 保护电路
- 输入 PMOS 防反接
- MCU 与继电器光耦隔离
- 可接阻性（R）或感性（L）负载
- API & 例程代码：Python API，完整例程代码
- 工作温度： -40 to 85 ℃
Figure 1 ERB4U-8 正面 | Figure 2 ERB4U-8 背面

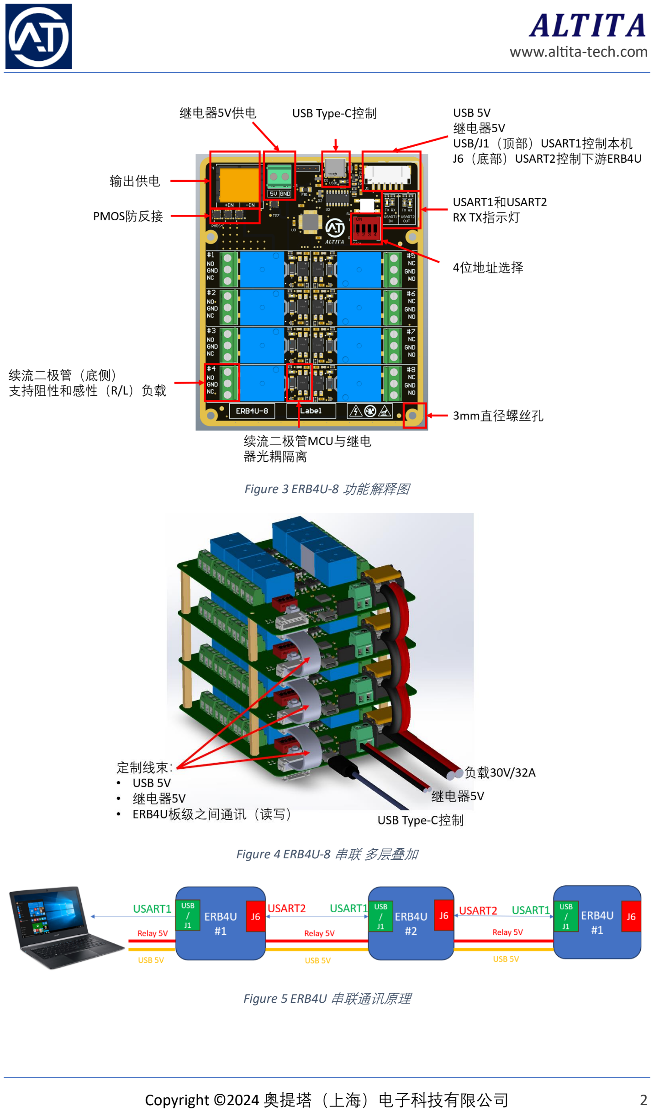
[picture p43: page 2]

Figure 3 ERB4U-8 功能解释图

Figure 4 ERB4U-8 串联 多层叠加

Figure 5 ERB4U 串联通讯原理

# 应用场景

- 工业自动化控制
- 自动化测试机
- 嵌入式电子设备
- 大学、科研机构、实验室
- 科创教育、培训机构

# 版本控制

版本号 | 发布时间 | 版本说明与变更
1.0 | 2024 年 5 月 1 号 | 初始发布版本
1.1 | 2024 年 5 月 30 号 | 添加读取 LDO VDDA 指令

目录

## 1 电气参数

### 1.1 继电器

- 继电器模块启动后，默认所有继电器关闭
- 1 路继电器输出最大 30VDC/10A，1NO + 1NC
- MCU 与继电器光耦隔离
- 继电器输出带 25ns 超高速续流二极管和电容，支持阻性负载和感性负载（例如电磁 阀，电机等）


Figure 6 继电器 30VDC/10A

## 1.2 地址设定

- 可通过 4 位拨码开关选择地址 0x00 – 0x0F

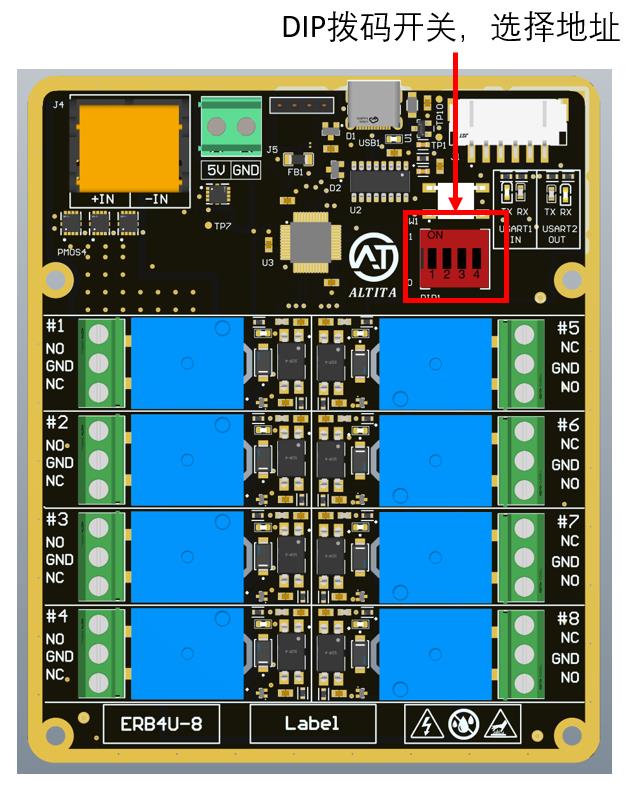
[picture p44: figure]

Figure 7 ERB4U 4 位 DIP 拨码开关 选择地址

### 1.3 USART 通讯

PC 端仅需 1 根 USB Type-C 数据线与 ERB4U 模块连接，即可实现 USART 串口读/写功能。

参数 | 数值
通信模式 | • USART1 连接到 USB Type-C 和 J1 连接器，用于和 PC 或上 游 ERB4U 继电器模块通讯 • USART2 连接到 J6 连接器，用于和下游 ERB4U 继电器模块 通讯
波特率 Baud rate | 115200
数据位数 Data bits | 8
停止位数 Stop bits | 1
奇偶校验 Parity | 奇校验
流控制 Flow Control | 无
如果继电器数量不够，可通过专用数据线（PN：S108520017，Ckmtw 灿科盟）把上游 ERB4U 的 J6 连接器，与下游 ERB4U 的 J1 连接器相连接，实现可扩展功能。工作原理如 下：
- USB 与 J1 连接器（顶部）与 USART1 连接。
- J6 连接器（底部）与 USART2 连接。
- 当 PC 端或上游 ERB4U 模块发出写指令后，下游 ERB4U 模块的 USB 或 J1 连接器 （USART1）会接收到指令，并把原指令通过 J6 连接器（USART2）发送给下一级 ERB4U，实现可扩展功能。
- 专用数据线用于传输 USB 5V 和继电器 5V 供电，同时也用于相邻 2 台 ERB4U 模块之间 的 USART RX/TX 通讯。
- 当 ERB4U 收到指令后，会检查自己的地址。如果地址符合，则 ERB4U 会执行相应动 作。如果地址不符合，则 ERB4U 不会执行指令。
- 具体 USART 指令，请参考<通讯协议>章节。

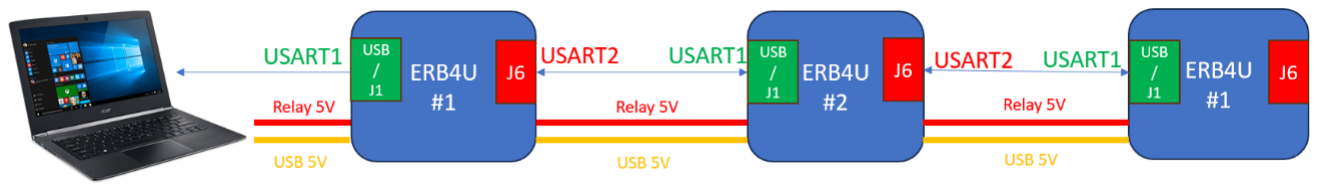
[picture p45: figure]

Figure 8 ERB4U 串联通讯原理

Figure 9 定制线束用于 ERB4U 通讯

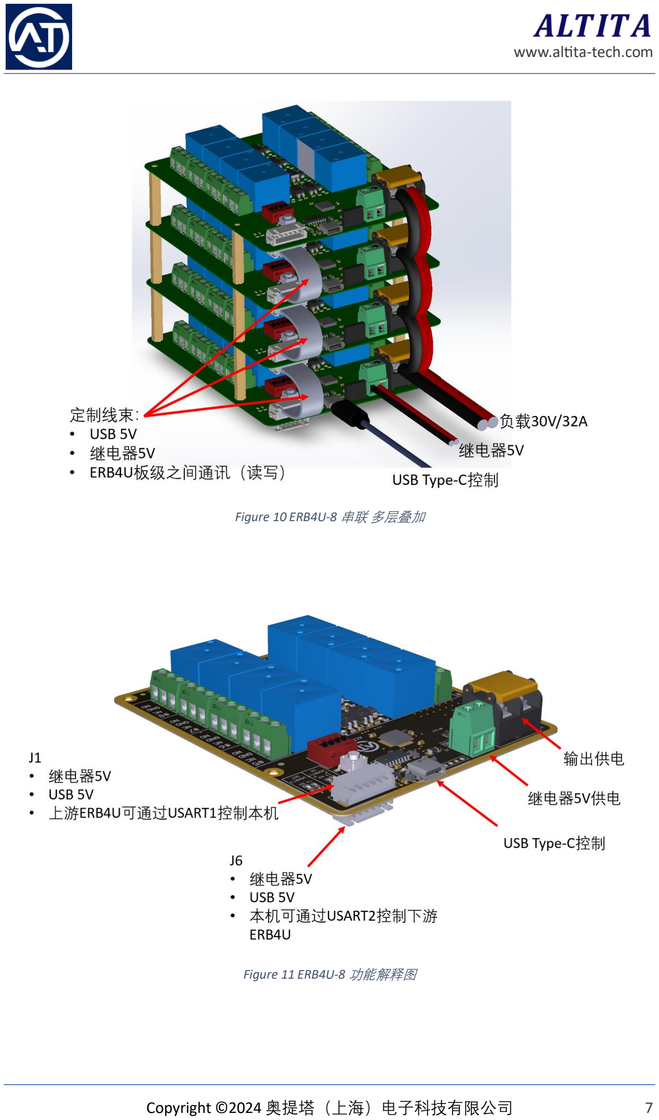
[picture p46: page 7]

Figure 10 ERB4U-8 串联 多层叠加

Figure 11 ERB4U-8 功能解释图

### 1.4 LED

- USB 供电：U 绿色 LED
- 继电器状态：绿色 LED
- USART1 TX：蓝色 LED
- USART1 RX：黄色 LED
- USART2 RX：蓝色 LED
- USART2 TX：黄色 LED

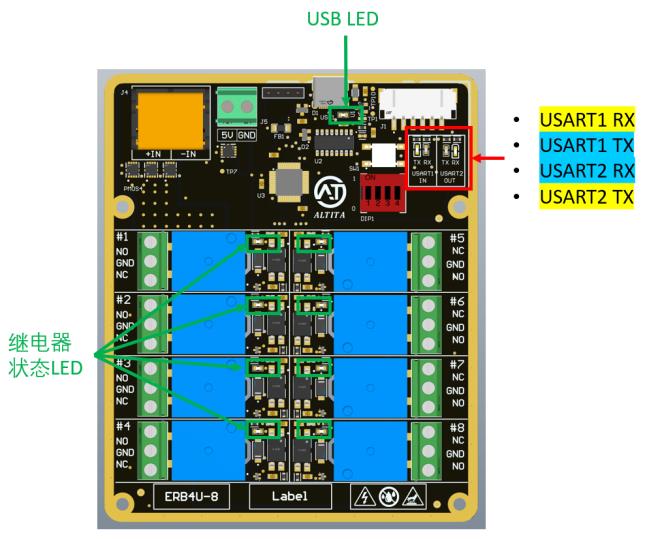
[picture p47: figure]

Figure 12 ERB4U-8 LEDs

## 1.5 复位按键

- 当复位按键按下后，MCU 重启，所有继电器会回到默认关闭状态。

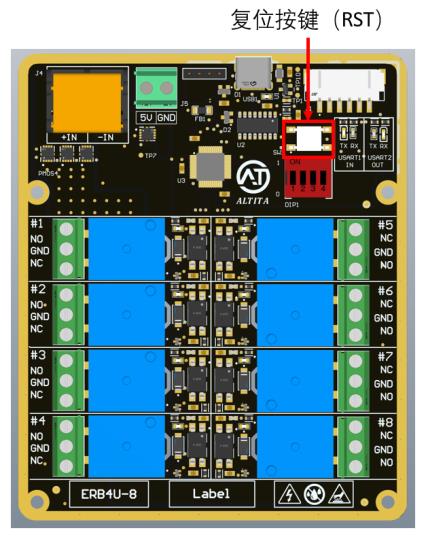
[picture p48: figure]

Figure 13 ERB4U-8 复位按键

## 1.6 工作温度

- 产品工作温度范围 -40 to 85 ℃
- MCU 内部温度传感器会采集温度值，可通过 UART 指令（Python API）读取数值。

## 2. 保护电路

### 2.1 输入 PMOS 防反接

- 继电器 5V 连接器和 DC 负载供电连接器，都装有了 PMOS 防反接保护。
- 由于 PMOS 存在导通电阻Rds_on，当电流通过 PMOS 时，PMOS 会发热。当 ERB4U 工作时，一般情况下 PMOS 会是 PCBA 上发热最严重的区域。温度计算公式如下

PMOS 温度 = 室温 + （负载电流^2）*0.4133

- 温度单位：摄氏度 ℃
- 电流单位：A

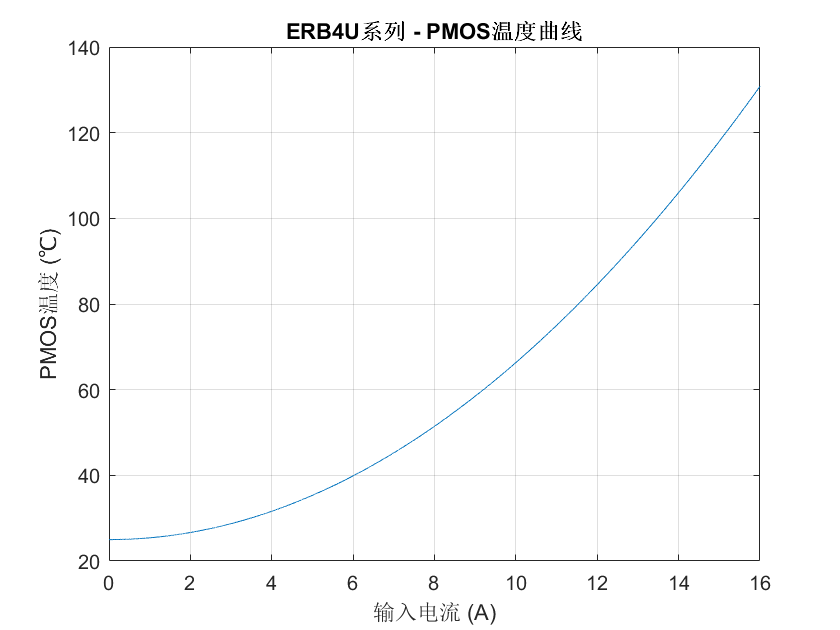
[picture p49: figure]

- 建议持续输入的总电流不超过 15A。
- 当输入总电流超过 15A 时，需要添加散热片或散热风扇。

## 2.2 MCU 与继电器光耦隔离

由于 MCU 是 3.3V 低电压，而负载输出一般是大电流的（例如 24VDC，10A），所以需要光 电三极管在中间进行光耦隔离，从而保护 MCU。

- MCU 通过 3.3V GPIO 打开光电三极管
- 光电三极管将 MCU 与继电器进行光耦隔离
- 光电三极管的输出是 5V，用来打开继电器

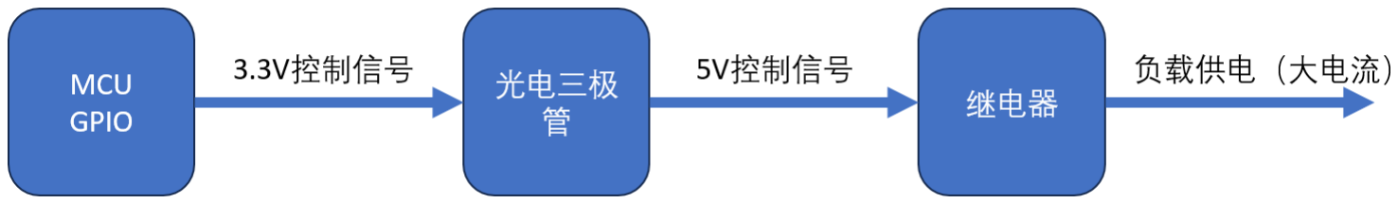
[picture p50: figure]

Figure 14 MCU 与继电器光耦隔离

## 2.3 可接阻性（R）或感性（L）负载

- 如果负载是感性负载（例如电磁阀，电机等），当当继电器关闭时，根据电感的特性， 感性负载会产生反向电动势，瞬间的反向电压会远超正常工作电压。
- 如果电流较大，甚至会拉出电弧。
- 长期使用后，会使继电器触点发黑或粘连，导致继电器无法正常打开或关闭。

为了解决以上问题，继电器的输入和输出端，都加入了 25ns 的超快速续流二极管。可在 25ns 内，快速释放掉电感的能量，解决反向电动势和电弧的问题。

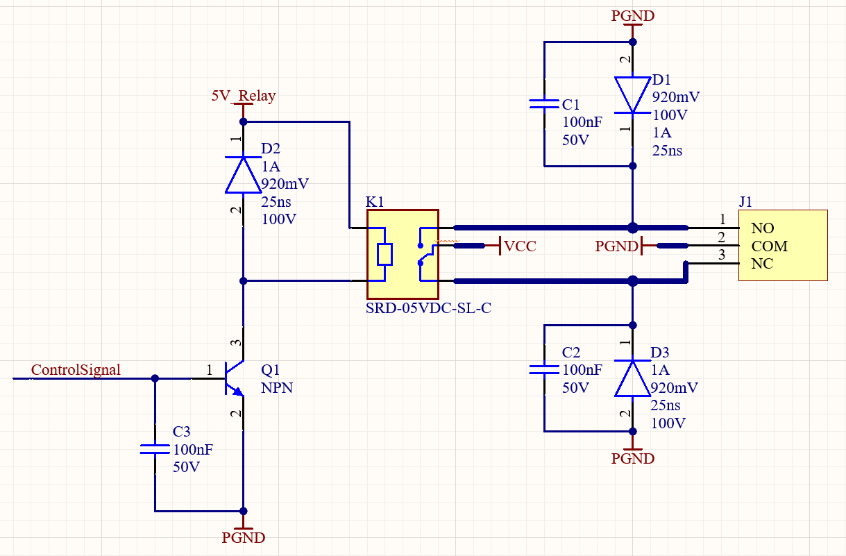
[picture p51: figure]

Figure 15 ERB4U 继电器原理图 支持 R/L 负载

## 3. 通讯协议

### 3.1 读指令

读指令
字节 | 指令 | 功能 | 备注
第 0 字 节 | 0x00 -0x0F | 产品地址，可通过板载 DIP 开关设 置 | /
第 1 字 节 | 0x00 | 读操作 | 如果既不是读操作（0x00）， 也不是写操作（0x01），会返 回报错： Error byte 1: unknown read/write operation
| 0x01 -0x08 | 读取指定继电器的状态 | 返回值： 1：继电器已打开 0：继电器已关闭
| 0xA0 | 读取所有继电器的状态 | 返回值： 如果总共有 8 个继电器，第 1 个继电器为 ON，其余继电 器为 OFF，则返回 “10000000”
| 0xA1 | 读取继电器数量 | 返回值： 如果总共有 8 个继电器，则 返回“8”
| 0xA2 | 读取 MCU 内部温度传感器 | 2 位小数（°C）
| 0xA3 | 读取 LDO VDDA 电压，额定电压 3.3V | 3 位小数（V）
| 0xF0 | 读取 PN | 可能的 PN 有： ERB4U-4 ERB4U-8 ERB4U-12
| 0xF1 | 读取 SN | 96 位 UUID
| 0xF2 | 读取硬件版本 | HW：X.Y.Z X = 主要硬件更改，例如添加 /删除组件 Y = 次要硬件更新，例如 PN 更改 Z = 补丁，例如错误修复
| 0xF3 | 读取固件版本 | FW：X.Y.Z X = 主要固件更改，例如新功 能或算法 Y = 次要固件更新，例如次要

第 2 字
节

| | | 功能改进 Z = 补丁，例如错误修复
| 其他 | 报错 | 返回值： Error byte 2: unknown read CMD
第 3 字 节 | 其他 | 未定义，可使用任意字节填补 | /

### 3.2 写指令

写指令
字节 | 指令 | 功能 | 备注
第 0 字 节 | 0x00 -0x0F | 产品地址，可通过板载 DIP 开关设 置 | /
第 1 字 节 | 0x01 | 写操作 | 如果既不是读操作 （0x00），也不是写操作 （0x01），会返回报错： Error byte 1: unknown read/write operation
第 2 字 节 | 0x01 -0x08 | 设置特定继电器的状态 | /
| 0xA0 | 关闭所有继电器 | /
| 0xA1 | 打开所有继电器 | /
| 其他 | 报错 | 返回值： Error byte 2: unknown write CMD
第 3 字 节 | 0x00 | 关闭指定继电器 | /
| 0x01 | 打开指定继电器 | /
| 其他 | 报错 | 返回值： Error byte 3: unknown relay state

## 3.3 故障信息

故障信息
字节 1 错误 | Error byte 1: unknown read/write operation
字节 2 错误 （读） | Error byte 2: unknown read CMD
字节 2 错误 （写） | Error byte 2: unknown write CMD
字节 3 错误 （写） | Error byte 3: unknown relay state

## 4. 功能方框图

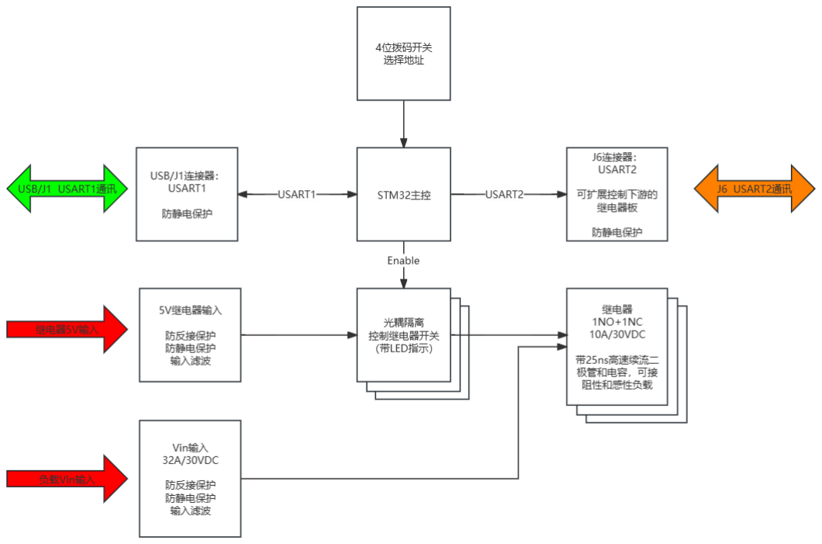
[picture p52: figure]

Figure 16 ERB4U 功能方框图

## 5. 产品图片

### 5.1 实物图

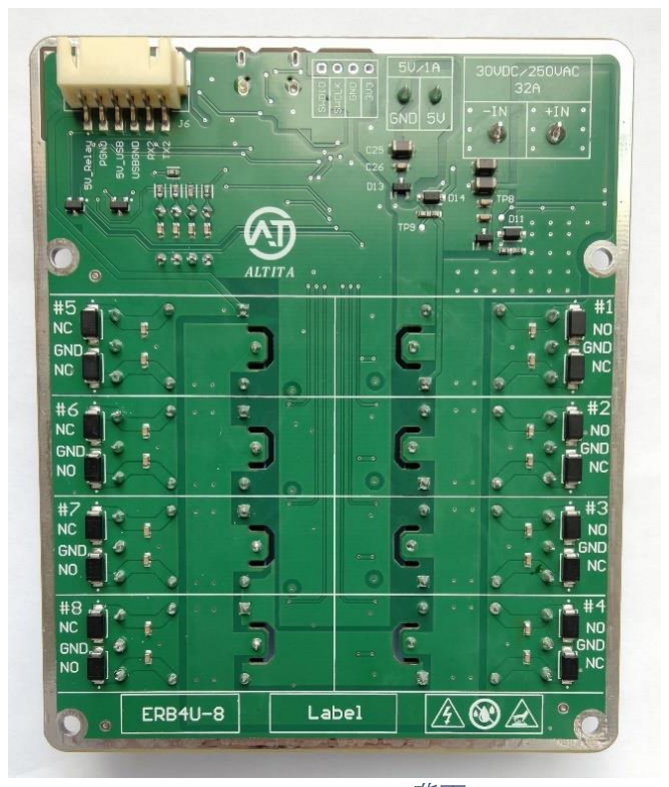
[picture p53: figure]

Figure 17 ERB4U-8 正面 | Figure 18 ERB4U-8 背面

### 5.2 2D 图纸

- 下载：DWG，DXF，PNG
- 单位：mm

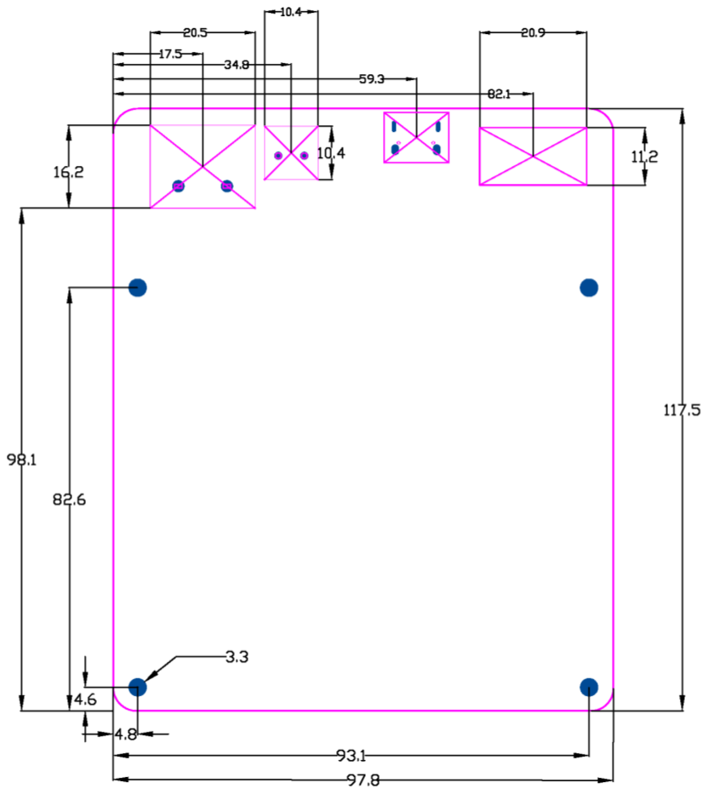
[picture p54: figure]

Figure 19 ERB4U-8 2D 图纸

### 5.3 3D 模型

- 下载：STEP

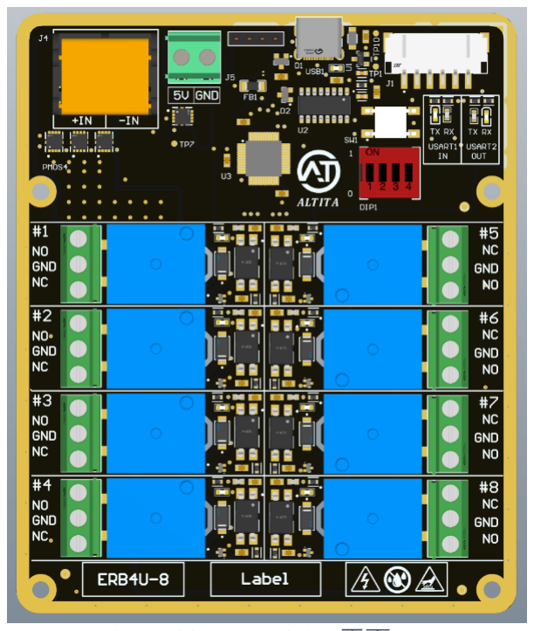
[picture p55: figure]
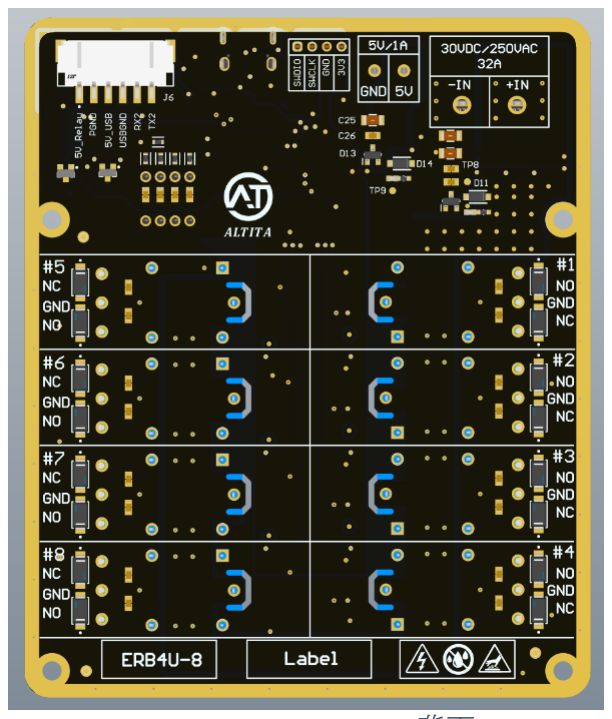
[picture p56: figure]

Figure 20 ERB4U-8 3D 正面 | Figure 21 ERB4U-8 3D 背面

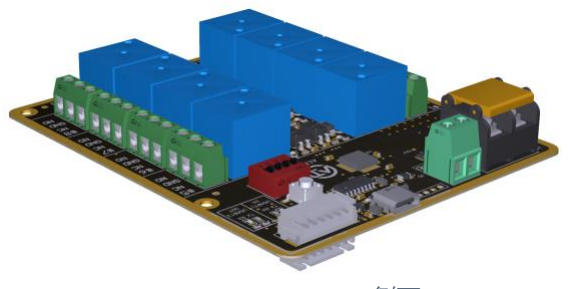
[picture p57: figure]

Figure 22 ERB4U-8 3D 侧面 | Figure 23 RB4U-8 3D 侧面

## 6. 例程代码和 API

- GitHub 链接 (https://github.com/altita-tech/ERB4U)

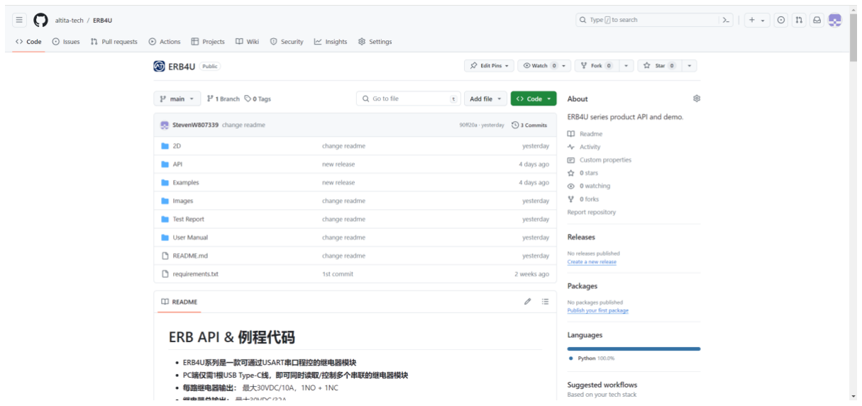
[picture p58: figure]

## 7. 测试报告

- 下载：ERB4U 测试报告模板

## 8. 联系方式

- 公司官网：https://altita-tech.com/
- 电话：+86 13512122992（销售董小姐）
- 微信：DL13512122992（销售董小姐）
- 销售：sales@altita-tech.com
- 技术支持：tech@altita-tech.com

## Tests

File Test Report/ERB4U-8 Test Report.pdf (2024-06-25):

# Test Report

Altita Electronics Technology 199 Jianchuan Rd, Shanghai, China Email: sales@altita-tech.com Website: www.altita-tech.com

Date | 2024-06-25 | Time | 11:14:42
Operator 1 | Li Dong | Operator 2 | Jixin Wang
PN | ERB4U-8 | SN | 35002A-48585309-20373338
Hardware | HW:0.0.2 | Firmware | FW:0.0.1
LDO (V) | 3.296 | Temperature | 35.77
Relay #1 | PASS | Relay #2 | PASS
Relay #3 | PASS | Relay #4 | PASS
Relay #5 | PASS | Relay #6 | PASS
Relay #7 | PASS | Relay #8 | PASS

### Copyright © 2024 Altita (Shanghai) Electronics Technology Co. Ltd

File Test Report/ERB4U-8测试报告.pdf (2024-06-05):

# 测试报告

奥提塔（上海）电子科技有限公司
中国上海市闵行区剑川路199号101室
邮箱：sales@altita-tech.com
网址：www.altita-tech.com
测试日期 | 2024-05-25 | 测试时间 | 22:27:22
测试人员 | 董莉 | 复核人员 | 王吉新
PN | ERB4U-8 | SN | 35002A-48585309-20373338
硬件版本 | HW:0.0.2 | 固件版本 | FW:0.0.1
LDO电压(V) | 3.297 | MCU温度(℃) | 34.31
继电器#1 | PASS | 继电器#2 | PASS
继电器#3 | PASS | 继电器#4 | PASS
继电器#5 | PASS | 继电器#6 | PASS
继电器#7 | PASS | 继电器#8 | PASS

Copyright © 2024 奥提塔（上海）电子科技有限公司

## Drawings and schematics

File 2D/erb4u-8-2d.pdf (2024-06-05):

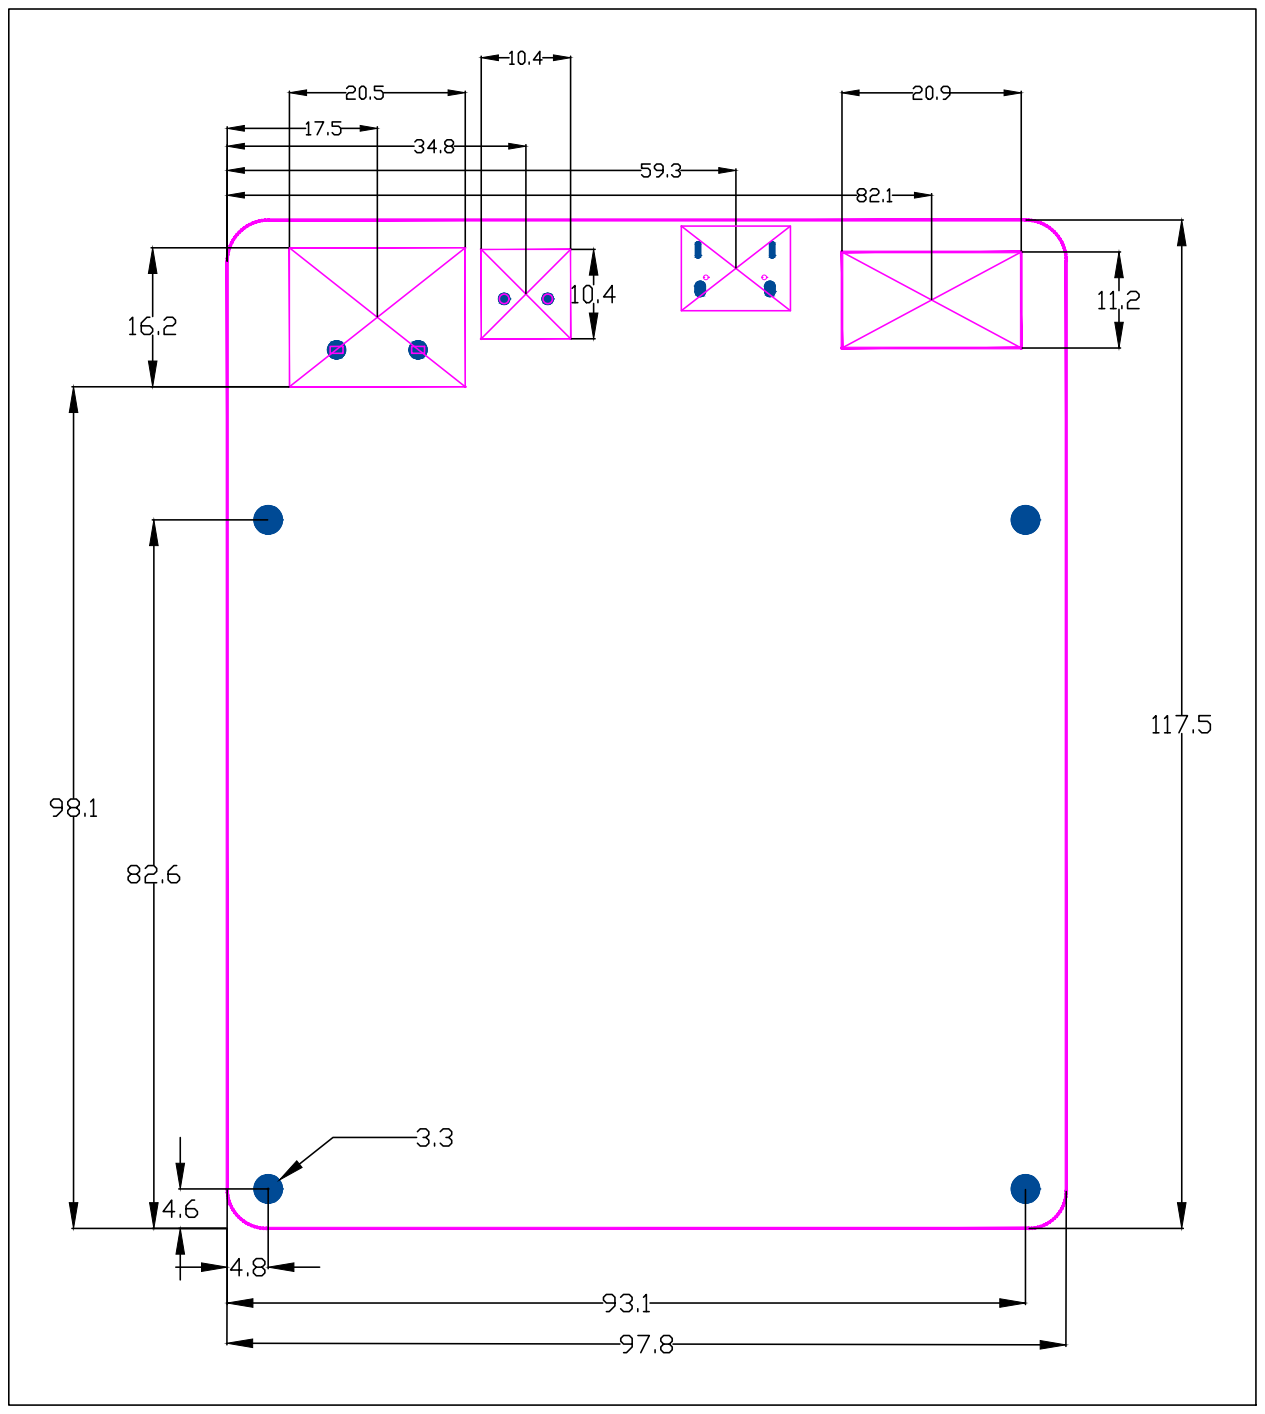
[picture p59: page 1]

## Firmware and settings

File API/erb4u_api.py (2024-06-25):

import serial
import time


class ERB4U:
    def __init__(self, port):
        self.port = port

        self.DONT_CARE_BYTE = 0xFF
        self.TIME_DELAY = 0.005
        
        self.ser = serial.Serial(self.port, 115200)
        self.ser.close()
        time.sleep(self.TIME_DELAY)

    def connect(self):
        self.ser.close()
        time.sleep(self.TIME_DELAY)
        self.ser.open()
        time.sleep(self.TIME_DELAY)
        print("connected")

    def disconnect(self):
        self.ser.close()
        time.sleep(self.TIME_DELAY)
        print("disconnected")

    def read_serial_data(self):
        data = self.ser.readline().decode('utf-8', errors='ignore').strip()
        if data:
            return data
        else:
            print("No available data")
            return None

    # Read commands ================================
    def read_relay_state(self, board_num: int, relay_num: int) -> int:
        cmd = bytes([board_num, 0x00, relay_num, self.DONT_CARE_BYTE])
        self.ser.write(cmd)
        relay_state = self.read_serial_data()
        time.sleep(self.TIME_DELAY)
        return int(relay_state)

    def read_all_relays_states(self, board_num: int) -> str:
        cmd = bytes([board_num, 0x00, 0xA0, self.DONT_CARE_BYTE])
        self.ser.write(cmd)
        all_relays_states = self.read_serial_data()
        time.sleep(self.TIME_DELAY)
        return all_relays_states

    def read_num_of_relay(self, board_num: int) -> int:
        cmd = bytes([board_num, 0x00, 0xA1, self.DONT_CARE_BYTE])
        self.ser.write(cmd)
        num_of_relay = self.read_serial_data()
        time.sleep(self.TIME_DELAY)
        return int(num_of_relay)

    def read_temperature_degree(self, board_num: int) -> float:
        cmd = bytes([board_num, 0x00, 0xA2, self.DONT_CARE_BYTE])
        self.ser.write(cmd)
        temperature_degree = float(self.read_serial_data())
        time.sleep(self.TIME_DELAY)
        return temperature_degree
    
    def read_ldo_vdda(self, board_num: int) -> float:
        cmd = bytes([board_num, 0x00, 0xA3, self.DONT_CARE_BYTE])
        self.ser.write(cmd)
        temperature_degree = float(self.read_serial_data())
        time.sleep(self.TIME_DELAY)
        return temperature_degree

    def read_pn(self, board_num: int) -> str:
        cmd = bytes([board_num, 0x00, 0xF0, self.DONT_CARE_BYTE])
        self.ser.write(cmd)
        pn = self.read_serial_data()
        time.sleep(self.TIME_DELAY)
        return pn
    
    def read_sn(self, board_num: int) -> str:
        cmd = bytes([board_num, 0x00, 0xF1, self.DONT_CARE_BYTE])
        self.ser.write(cmd)
        sn = self.read_serial_data()
        time.sleep(self.TIME_DELAY)
        return sn

    def read_hardware_rev(self, board_num: int) -> str:
        cmd = bytes([board_num, 0x00, 0xF2, self.DONT_CARE_BYTE])
        self.ser.write(cmd)
        hardware_rev = self.read_serial_data()
        time.sleep(self.TIME_DELAY)
        return hardware_rev

    def read_firmware_rev(self, board_num: int) -> str:
        cmd = bytes([board_num, 0x00, 0xF3, self.DONT_CARE_BYTE])
        self.ser.write(cmd)
        firmware_rev = self.read_serial_data()
        time.sleep(self.TIME_DELAY)
        return firmware_rev


    # Write commands ================================
    def turn_off_relay(self, board_num: int, relay_num: int) -> None:
        cmd = bytes([board_num, 0x01, relay_num, 0x00])
        self.ser.write(cmd)
        time.sleep(self.TIME_DELAY)
        
    def turn_on_relay(self, board_num: int, relay_num: int) -> None:
        cmd = bytes([board_num, 0x01, relay_num, 0x01])
        self.ser.write(cmd)
        time.sleep(self.TIME_DELAY)

    def turn_off_all_relays(self, board_num: int) -> None:
        cmd = bytes([board_num, 0x01, 0xA0, 0x00])
        self.ser.write(cmd)
        time.sleep(self.TIME_DELAY)

    def turn_on_all_relays(self, board_num: int) -> None:
        cmd = bytes([board_num, 0x01, 0xA1, 0x01])
        self.ser.write(cmd)
        time.sleep(self.TIME_DELAY)

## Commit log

2024-06-05 change readme
    [ERB4U-8.DWG, ERB4U-8.dxf]
2024-06-25 add CN/EN languages README
    [ERB4U-8.DWG, ERB4U-8.dxf, ERB4U-Communication-Protocol.xlsx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]
